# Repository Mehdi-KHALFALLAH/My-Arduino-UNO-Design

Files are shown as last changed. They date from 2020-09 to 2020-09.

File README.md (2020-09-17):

# My-Arduino-UNO-Design

## Contents and Overview

During this project, I deepened and honed my knowledge about ***Altium Designer*** (Version 20.0.10) software and how to do professional PCB design. Altium Designer is a professional software used to design all kinds of boards, from very simple ones to motherboards or servers. It is one of the most used software for electronic design.

I started with Arduino Uno reference schematic. I learned how to re-draw the schematic, modify it, I learned how to improve it and how to do PCB layout. and by the end of the project, I learned what documents are necessary to manufacture the board and how to create them.

during this project, I learned how :

- Draw schematic, including tips for component selection and important circuits
- Create components, draw schematic symbols and footprints
- Place components into your PCB
- Route PCB and useful tips about layout
- Create a 3D model of your board
- Create board variants with different components fitted / not fitted
- Create Bill of Material (BOM)
- Create assembly drawings showing the position of components on the board
- Generate Gerbers, Pick and Place, Drill file, and other files needed for manufacturing
- Prepare professional documents needed to manufacture your PCB and assemble your board

 ## Summary of my project
 
 ### table of contents
 <br />
 
 ***I.  [ Creating my own libraries (schematics, footprints and adding a 3D model to each component) ](#desc)***
 
 ***II. [ Components placement ](#usage)***
 
 ***III. [ Layer's stackup ](#easy)***
 
 ***IV.  [ PCB Layout & Routing ](#hard)***

 ***V.  [ Gerber files, mechanical and assembly drawing ](#medium)***

***VI.   [ 3D model ](#day)***

***VII.  [ VII. Electromagnetic and Signal Integrity (SI) analysis and current density plot with ***ANSYS SIwave***  ](#night)***
<br />
<br />
<br />
<br />
<br />
<br />

## I. Creating my own libraries (schematics, footprints and adding a 3D model to each component)
 
 ### 1 - Designing my first component : the ATMEGA16U2-AU 
 Drawing the schematic and generating the footprint in my own using the Altium tool ***"footprint wizard"***. 
 P.S: footprint's dimensions are taken from the component datasheet :
 
 ATMEGA16U2-AU
 
 ### 2 - Designing the second component : the ATMEGA328P-PU
 
 ATMEGA328P-PU
 
 ### 3 - Designing the female header 1 row x 10 positions (pins)
 
 Female_Header_10Pins
 
 ### 4 - Designing the female header 1 row x 8 positions (pins)
 
8 Pos Female SIL Vertical Throughboard Conn

 ### 5 - Designing the female header 1 row x 6 positions (pins)
 
 Female_Header_6Pins
 
 ### 5 - Designing the 100nF capacitor 
 
 CAP 100n
 
 ### 6 - Sesigning the 10uF capacitor with 1.45mm height 
 
 Cap 10uF_145_height

### 7 - Designing the 1M resistor 

Resistor_1M

### 8 - Designing the 16Mhz crystal 

16MHz Crystal

### 9 - Designing the Micro USB 

micro_USB

### 10 - Designing the 100uf aluminum clectrolytic Capacitor

alu cap 100uf

### 11 - Designing the linear regulator 3.3V 1.5A

regulator

### 12 - Designing the AND gate 

and gate

### 13 - Designing the Button

button

### 14 - Designing the LED 

LED

### 15 - Designing the male header 2 rows x 3 positions (pins)

header 2w3

### 16 - Designing the male header 2 x 2

male 2x2

### 17 - Designing the male header 1 x 3

1x3 header

### 18 - Successful compilation of the project's schematics

0 error

## II. Components placement

### 19 - Starting the placement of some components on the board 

work in progress more 273 component to place

### 20 - Placement of half of the components
By taking advantage of the altium's features cross probe and components cross selection, i could select components from shematic sheet and at the same time they are selected in the PCB sheet, which make it easier to put couplage capacitors as close as possible to their power pins  

half way

### 21 - Placement of the components is complete 

placement complete_blue

## III. Layer's stackup

### 22 - Layer's stackup in 3D  
standard  dielectric thickness   : 1.6mm 
layer 3D

## IV. PCB Layout & Routing

### 23 - Starting to route long tracks

Starting to route long connections first

### 24 - Routing some long tracks through 2 layers
using vias to go from one layer to onother, I call this the "ping pong" routing

### 25 - Routing 2 tracks through 2 layers (some imporvements are made)

routing 2 connections through 2 layers ( some imporvements are done )

### 26 - Finished routing long connections, short connections and Power connections (Power connections are highlighted in the picture)

Finished routing long connections, short connections and Power connections (Power connections are highlighted in the picture)

### 27 - Finished routing all the connections on the board and debugging and fixing all violations errors one by one

Finished routing all the connections on the board and debugging and fixing all violations errors one by one

### 28 - All rule violations are fixed and the board is validated with 0 errors

all rule violations are fixed and the board is validated with 0 errors

### 29 - Drawing the power and the ground planes on the bottom layer

drawing the power and Ground planes on the bottom layer

### 30 - DRC check with 0 errors after improving layout and finishing drawing power and ground planes

DRC check 0 errors after imroving layout and finishing drawing power and ground planes

### 31 - PCB layout after doing some improvements and drawing all the power and ground planes

PCB layout after doing some improvments and drawing power and ground planes

### 32 - Bottom overlay

bottom overlay

### 33 - Last compile after completing the layout 

Last compile, last check

### 34 - Last design rule check after finishing the layout 

Last design rule check

## V. Gerber files, mechanical and assembly drawing

### 35 - Gerber top layer

Gerber Top Layer

### 36 - Gerber bottom layer

Gerber bottom Layer

### 37 - Gerber top overlay

Gerber Top Overlay

### 38 - Gerber bottom overlay

Gerber Bottom Overlay

### 39 - Gerber mechanical drawing

Gerber Mechanical Drawing

### 40 - Generated PDF mechanical drawing

Generated PDF Mechanical Drawing

### 41 - Generated PDF of the assembly drawing variant fixed 5V

Assembly drawing variant fixed 5

### 42 - Generated PDF of the assembly drawing variant 5V 3V3

Assembly drawing variant 5V 3V3

### 43 - Generated PDF of the assembly top view fixed 5V 

Assembly top view 5V fixed

### 44 - Generated PDF of the assembly top view 5V 3V3

Assembly top view 5V 3V3

## VI. 3D model

### 45 - 3D model of my board in Altium Designer

3D Model in Altium
board behind

## VII. Electromagnetic and Signal Integrity (SI) analysis and current density plot with ***ANSYS SIwave*** 

### 46 - Current density analysis using ANSYS SIwave 

using the advanced simulation software especially designed for PCBs, i could do a current density analysis and generate an easy-to-understand plot

Current-Voltage analysis using SIwave from Ansys

### 47 - Far end crosstalk analysis between traces

far end crosstalk between traces

### 48 - Near end crosstalk violations and warnings

near end crosstalk violations and warnings

### 49 - Trace impedance analysis

trace impedance analysis, some improvements and fixes must be done

trace inpedance analisys, some imporvlements and fices must be done

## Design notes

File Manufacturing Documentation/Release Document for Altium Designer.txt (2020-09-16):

Follow this procedure before releasing files. Confirm every action with your initials and date.
IF ANY CHANGES NEEDS TO BE DONE, START THE PROCEDURE FROM BEGINNING!

The procedure needs to be executed in order as defined here. Start from number 1
--------------------------------------------------------------------------------

1) Right Click on the project -> Compile PCB project
I confirm, the project compiles with no errors: 
YourIntials [12:02:52  08/09/2020]

2) Run Design -> Update PCB Document
I confirm, there are no differences between Schematic and PCB: 
YourIntials [12:05:29  08/09/2020]

3) Impedance
I confirm, I have updated and check track width/gap to match required impedance (e.g 55 OHMs): 
NA

4) Run Tools -> Polygon Pours -> Rebuild All
I confirm, all polygons have been repoured: 
YourIntials [12:06:42  08/09/2020]

5) Run Tools -> Design Rule Check -> Run Design Rule Check
I confirm, I have checked Design Rule Output File:
YourIntials [12:33:11  08/09/2020]

6) Gerber check
I confirm, I have copied and visually checked gerber files placed in \PCB Manufacturing\Gerber Output\
YourIntials [17:27:11  08/09/2020]

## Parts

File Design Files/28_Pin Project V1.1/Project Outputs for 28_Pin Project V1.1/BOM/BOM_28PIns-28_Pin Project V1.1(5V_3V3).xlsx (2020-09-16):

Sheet: Part List Report
 | Component list |  |  | 28PIns BOM for Variant [5V/3V3] of Project [28_Pin Project V1.1.PrjPcb] (No PCB Document Selected)
 | Source Data From: | 28_Pin Project V1.1.PrjPcb |  |  | Contact : contact.mehdi.khalfallah@gmail.com |  |  | Generated by:
 | Project: | 28_Pin Project V1.1.PrjPcb
 | Variant: | 5V/3V3 |  |  |  |  |  | Ingr.Mehdi Khalfallah
 | Report Date: | 08/09/2020 | 21:15
 | Print Date: | 2020-09-09 | 18:02:05
# | Category | Manufacturer 1 | Manufacturer Part Number 1 | #Column Name Error:' Package / Case | Description | Quantity | Supplier 1 | Supplier Part Number 1 | Supplier Order Qty 1 | Supplier Stock 1 | Supplier Unit Price 1 | Supplier Subtotal 1 | Supplier Currency 1
1 | Aluminum Electrolytic Capacitors |  |  |  | Cap Aluminum 100uF 10V 20% (5 X 5.4mm) SMD 50mA 1000 hr 85°C T/R | 2 | Digi-Key | PCE3867CT-ND
2 | Ceramic Capacitors |  |  |  | TDK - C2012X5R1E105K125AA - SMD Multilayer Ceramic Capacitor, 1 µF, 25 V, 0805 [2012 Metric], ± 10%, X5R, C Series | 1 | Digi-Key | 445-1419-1-ND
3 | Ceramic Capacitors |  |  |  | CERAMIC CAPACITOR, 10UF, 16V, X5R, 20%, 0805, FULL REEL; Product Range:C Series; Capacitance:10 F; Capacitance Tolerance: 20%; Dielectric Characteristic:X5R; Voltage Rating:16V; Ceramic Capacitor Case:0805 [2012 Metric]; MSL:- ;RoHS Compliant: Yes | 7 | Digi-Key | 445-4115-1-ND
4 | Ceramic Capacitors |  |  |  | CAP CER 18PF 50V C0G/NP0 0805 | 4 | Digi-Key | 399-1112-1-ND
5 | Ceramic Capacitors |  |  |  | TDK - C2012X7R1H104K085AA - SMD Multilayer Ceramic Capacitor, 0.1 µF, 50 V, 0805 [2012 Metric], ± 10%, X7R, C Series | 19 | Digi-Key | 445-7534-1-ND
6 | Chip SMD Resistors |  |  |  | Surface Mount Thick Film Resistor, RC Series, 125 mW, - 5%, 150 V, 0805 [2012 Metric] | 1 | Digi-Key | 311-0.0ARCT-ND
7 | Chip SMD Resistors |  |  |  | RESISTOR, 0805 1K 1%, FULL REEL; Product Range:YAGEO - RC Series; Resistance:1kohm; Power Rating:125mW; Resistance Tolerance:± 1%; Resistor Case Style:0805 [2012 Metric]; Resistor Element Material:Thick Film; Temperature Coefficient:± 250ppm/°C; Voltage Rating:150V; Packaging:Tape & Reel; MSL:-; SVHC:No SVHC (16-Dec-2013); External Depth:0.55mm; External Length / Height:2mm; External Width:1.25mm; No. of Pins:2; Operating Temperature Max:155°C; Operating Temperature Min:-55°C; Operating Temperature Range:-55°C to +155°C; Reel Quantity:5000; Resistor Mounting:SMD; Series:RC12H; Temperature Coef | 3 | Digi-Key | 311-1.00KCRCT-ND
8 | Chip SMD Resistors |  |  |  | Res Thick Film 0805 1M Ohm 1% 0.125W(1/8W) ±100ppm/C Epoxy SMD T/R | 2 | Digi-Key | 311-1.00MCRDKR-ND
9 | Chip SMD Resistors |  |  |  | RES SMD 10K OHM 1% 1/8W 0805 | 6 | Digi-Key | 311-10.0KCRDKR-ND
10 | Chip SMD Resistors |  |  |  | RES SMD 22 OHM 1% 1/8W 0805 | 7 | Digi-Key | 311-22.0CRCT-ND
11 | Chip SMD Resistors |  |  |  | YAGEO RC0805FR-07100KL RES, THICK FILM, 100K, 1%, 0.125W, 0805, REEL | 1 | Digi-Key | 311-100KCRCT-ND
12 | Chip SMD Resistors |  |  |  | Surface Mount Thick Film Resistor, RC Series, 560 ohm, 125 mW, - 1%, 150 V, 0805 [2012 Metric] | 5 | Digi-Key | 311-560CRCT-ND
13 | Connectors |  |  |  | CONN IC DIP SOCKET 28POS TIN | 1 | Digi-Key | 3M5480-ND
14 | Connectors |  |  |  | CONN JUMPER SHORTING .100" GOLD | 3 | Digi-Key | S9337-ND
15 | Crystals |  |  |  | ABRACON - ABM7-8.000MHZ-D2Y-T - Crystal, Miniature, 8 MHz, SMD, 6mm x 3.5mm, 30 ppm, 18 pF, 20 ppm, ABM7 Series | 1 | Digi-Key | 535-9831-1-ND
16 | Crystals |  |  |  | CRYSTAL 10.0000MHZ 18PF SMD | 1 | Digi-Key | 535-9833-1-ND
17 | Ferrite Beads and Chips |  |  |  | FERRITE BEAD 600 OHM 0805 1LN | 3 | Digi-Key | 445-2206-2-ND
18 | Fixed Inductors |  |  |  | FIXED IND 2.2UH 2A 80 MOHM SMD | 1 | Digi-Key | 399-9598-1-ND
19 | Headers and Wire Housings |  |  |  | CONN HEADER VERT 4POS 2.54MM | 1 | Digi-Key | 609-3402-ND
20 | Headers and Wire Housings |  |  |  | CONN HEADER 6POS .100 STR 30AU | 2 | Digi-Key | 609-3393-ND
21 | Headers and Wire Housings |  |  |  | Conn Unshrouded Header HDR 3 POS 2.54mm Solder ST Thru-Hole Bulk | 2 | Digi-Key | 609-3461-ND
22 | Headers and Wire Housings |  |  |  | 2.54mm (0.1") Pitch SIL Vertical PC Tail Socket Assembly, selective gold + tin, 8 contacts | 2 | Digi-Key | 952-1823-ND
23 | Headers and Wire Housings |  |  |  | 06-WAY SIL VERT SOCKET L/FREE | 1 | Digi-Key | 952-1809-ND
24 | Headers and Wire Housings |  |  |  | HARWIN - M20-7821046 - Board-To-Board Connector, M20 Series, Through Hole, Receptacle, 10, 2.54 mm, Tin Plated Contacts | 1 | Digi-Key | 952-1847-ND
25 | Logic Gates |  |  |  | TEXAS INSTRUMENTS - SN74AHC1G09DBVR - AND Gate, 74AHC1G09, 2 Input, 2 V to 5.5 V, SOT-23-5 | 4 | Digi-Key | 296-29202-1-ND
26 | Microcontrollers |  |  |  | MICROCHIP - ATMEGA16U2-AU - MCU, 8BIT, MEGAAVR, 16MHZ, TQFP-32 | 1 | Digi-Key | ATMEGA16U2-AU-ND
27 | Microcontrollers |  |  |  | ATMEGA328P-PU; 8 bit Microcontroller AVR 20MHz 1; 32kb Flash; 2kb RAM; I2C SPI 2 | 1 | Digi-Key | ATMEGA328P-PU-ND
28 | Pushbutton Switches |  |  |  | SWITCH TACTILE SPST-NO 0.05A 24V | 2 | Digi-Key | 450-1650-ND
29 | Schottky Diodes |  |  |  | Small Signal Schottky Diode, Single, 30 V, 200 mA, 800 mV, 600 mA, 150 C ;RoHS Compliant: Yes | 2 | Digi-Key | BAT54HT1GOSCT-ND
30 | Uncategorized |  |  |  | LED Uni-Color Green 572nm 2-Pin Chip 0603(1608Metric) T/R | 1 | Digi-Key | 475-2709-1-ND
31 | Uncategorized |  |  |  | OSRAM - LO L29K-H2K1-24-Z - SMARTLED 0603 ORANGE | 3 | Digi-Key | 475-2740-1-ND
32 | USB Connectors |  |  |  | CONN USB MICRO B RECPT SMT R/A | 1 | Digi-Key | 609-4616-1-ND
33 | Varistors |  |  |  | VARISTOR 0603 | 2 | Digi-Key | CG0603MLC-05ECT-ND
34 | Voltage Regulators - Linear |  |  |  | IC REG LINEAR 3.3V 1.5A SOT223-6 | 1 | Digi-Key | 296-24534-1-ND
 |  |  |  |  |  | 95 |  |  | 0 |  |  | 0
Approved |  |  |  | Notes
 |  |  |  |  |  | 1000 | pcs: | Total |  | 0 |  | USD
 |  |  |  |  |  |  |  | Price for 1pcs |  | 0.00 |  | USD

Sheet: Project Information
Project Full Path | C:\Users\USER\Desktop\altium designer projects\28Pins\Design Files\28_Pin Project V1.1\28_Pin Project V1.1.PrjPcb
Project Filename | 28_Pin Project V1.1.PrjPcb
Variant Name | 5V/3V3
Data-Source Filename | 28_Pin Project V1.1.PrjPcb
Data-Source Full Path | C:\Users\USER\Desktop\altium designer projects\28Pins\Design Files\28_Pin Project V1.1\28_Pin Project V1.1.PrjPcb
Title | 28PIns BOM for Variant [5V/3V3] of Project [28_Pin Project V1.1.PrjPcb] (No PCB Document Selected)
Total Quantity | 95
Report Time | 21:15
Report Date | 08/09/2020
Report Date & Tine | 08/09/2020 21:15
Output Name | 28PIns BOM
Output Type | BOM_PartType
Output Generator Name | BOM
Output Generator Description | Bill of Materials

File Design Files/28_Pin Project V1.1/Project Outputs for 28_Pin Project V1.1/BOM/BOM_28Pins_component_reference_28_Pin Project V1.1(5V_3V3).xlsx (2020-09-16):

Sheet: Part List Report
 | Component reference list |  |  | <Parameter Project not found>
 |  | Source Data From: | 28_Pin Project V1.1.PrjPcb | Contact: contact.mehdi.khalfallah@gmail.com |  | Generated by:
 |  | Project: | 28_Pin Project V1.1.PrjPcb
 |  | Variant: | 5V/3V3 |  |  | Ingr.Mehdi Khalfallah
 | Report Date: | 08/09/2020 | 21:13
 | Print Date: | 2020-09-09 | 17:57:16
# | Designator | Comment | Description | Manufacturer 1 | Manufacturer Part Number 1 | #Column Name Error:' Package / Case | Supplier 1 | Supplier Part Number 1
1 | C1 | 100uF/10V | Cap Aluminum 100uF 10V 20% (5 X 5.4mm) SMD 50mA 1000 hr 85°C T/R |  |  |  | Digi-Key | PCE3867CT-ND
2 | C2 | 100uF/10V | Cap Aluminum 100uF 10V 20% (5 X 5.4mm) SMD 50mA 1000 hr 85°C T/R |  |  |  | Digi-Key | PCE3867CT-ND
3 | C3 | 10uF/16V | CERAMIC CAPACITOR, 10UF, 16V, X5R, 20%, 0805, FULL REEL; Product Range:C Series; Capacitance:10 F; Capacitance Tolerance: 20%; Dielectric Characteristic:X5R; Voltage Rating:16V; Ceramic Capacitor Case:0805 [2012 Metric]; MSL:- ;RoHS Compliant: Yes |  |  |  | Digi-Key | 445-4115-1-ND
4 | C4 | 100nF | TDK - C2012X7R1H104K085AA - SMD Multilayer Ceramic Capacitor, 0.1 µF, 50 V, 0805 [2012 Metric], ± 10%, X7R, C Series |  |  |  | Digi-Key | 445-7534-1-ND
5 | C5 | 100nF | TDK - C2012X7R1H104K085AA - SMD Multilayer Ceramic Capacitor, 0.1 µF, 50 V, 0805 [2012 Metric], ± 10%, X7R, C Series |  |  |  | Digi-Key | 445-7534-1-ND
6 | C6 | 100nF | TDK - C2012X7R1H104K085AA - SMD Multilayer Ceramic Capacitor, 0.1 µF, 50 V, 0805 [2012 Metric], ± 10%, X7R, C Series |  |  |  | Digi-Key | 445-7534-1-ND
7 | C7 | 1u/25V | TDK - C2012X5R1E105K125AA - SMD Multilayer Ceramic Capacitor, 1 µF, 25 V, 0805 [2012 Metric], ± 10%, X5R, C Series |  |  |  | Digi-Key | 445-1419-1-ND
8 | C8 | 100nF | TDK - C2012X7R1H104K085AA - SMD Multilayer Ceramic Capacitor, 0.1 µF, 50 V, 0805 [2012 Metric], ± 10%, X7R, C Series |  |  |  | Digi-Key | 445-7534-1-ND
9 | C9 | 18p | CAP CER 18PF 50V C0G/NP0 0805 |  |  |  | Digi-Key | 399-1112-1-ND
10 | C10 | 18p | CAP CER 18PF 50V C0G/NP0 0805 |  |  |  | Digi-Key | 399-1112-1-ND
11 | C11 | 100nF | TDK - C2012X7R1H104K085AA - SMD Multilayer Ceramic Capacitor, 0.1 µF, 50 V, 0805 [2012 Metric], ± 10%, X7R, C Series |  |  |  | Digi-Key | 445-7534-1-ND
12 | C12 | 10uF/16V | CERAMIC CAPACITOR, 10UF, 16V, X5R, 20%, 0805, FULL REEL; Product Range:C Series; Capacitance:10 F; Capacitance Tolerance: 20%; Dielectric Characteristic:X5R; Voltage Rating:16V; Ceramic Capacitor Case:0805 [2012 Metric]; MSL:- ;RoHS Compliant: Yes |  |  |  | Digi-Key | 445-4115-1-ND
13 | C13 | 10uF/16V | CERAMIC CAPACITOR, 10UF, 16V, X5R, 20%, 0805, FULL REEL; Product Range:C Series; Capacitance:10 F; Capacitance Tolerance: 20%; Dielectric Characteristic:X5R; Voltage Rating:16V; Ceramic Capacitor Case:0805 [2012 Metric]; MSL:- ;RoHS Compliant: Yes |  |  |  | Digi-Key | 445-4115-1-ND
14 | C14 | 100nF | TDK - C2012X7R1H104K085AA - SMD Multilayer Ceramic Capacitor, 0.1 µF, 50 V, 0805 [2012 Metric], ± 10%, X7R, C Series |  |  |  | Digi-Key | 445-7534-1-ND
15 | C15 | 100nF | TDK - C2012X7R1H104K085AA - SMD Multilayer Ceramic Capacitor, 0.1 µF, 50 V, 0805 [2012 Metric], ± 10%, X7R, C Series |  |  |  | Digi-Key | 445-7534-1-ND
16 | C16 | 100nF | TDK - C2012X7R1H104K085AA - SMD Multilayer Ceramic Capacitor, 0.1 µF, 50 V, 0805 [2012 Metric], ± 10%, X7R, C Series |  |  |  | Digi-Key | 445-7534-1-ND
17 | C17 | 100nF | TDK - C2012X7R1H104K085AA - SMD Multilayer Ceramic Capacitor, 0.1 µF, 50 V, 0805 [2012 Metric], ± 10%, X7R, C Series |  |  |  | Digi-Key | 445-7534-1-ND
18 | C19 | 10uF/16V | CERAMIC CAPACITOR, 10UF, 16V, X5R, 20%, 0805, FULL REEL; Product Range:C Series; Capacitance:10 F; Capacitance Tolerance: 20%; Dielectric Characteristic:X5R; Voltage Rating:16V; Ceramic Capacitor Case:0805 [2012 Metric]; MSL:- ;RoHS Compliant: Yes |  |  |  | Digi-Key | 445-4115-1-ND
19 | C20 | 100nF | TDK - C2012X7R1H104K085AA - SMD Multilayer Ceramic Capacitor, 0.1 µF, 50 V, 0805 [2012 Metric], ± 10%, X7R, C Series |  |  |  | Digi-Key | 445-7534-1-ND
20 | C21 | 10uF/16V | CERAMIC CAPACITOR, 10UF, 16V, X5R, 20%, 0805, FULL REEL; Product Range:C Series; Capacitance:10 F; Capacitance Tolerance: 20%; Dielectric Characteristic:X5R; Voltage Rating:16V; Ceramic Capacitor Case:0805 [2012 Metric]; MSL:- ;RoHS Compliant: Yes |  |  |  | Digi-Key | 445-4115-1-ND
21 | C22 | 10uF/16V | CERAMIC CAPACITOR, 10UF, 16V, X5R, 20%, 0805, FULL REEL; Product Range:C Series; Capacitance:10 F; Capacitance Tolerance: 20%; Dielectric Characteristic:X5R; Voltage Rating:16V; Ceramic Capacitor Case:0805 [2012 Metric]; MSL:- ;RoHS Compliant: Yes |  |  |  | Digi-Key | 445-4115-1-ND
22 | C23 | 100nF | TDK - C2012X7R1H104K085AA - SMD Multilayer Ceramic Capacitor, 0.1 µF, 50 V, 0805 [2012 Metric], ± 10%, X7R, C Series |  |  |  | Digi-Key | 445-7534-1-ND
23 | C24 | 100nF | TDK - C2012X7R1H104K085AA - SMD Multilayer Ceramic Capacitor, 0.1 µF, 50 V, 0805 [2012 Metric], ± 10%, X7R, C Series |  |  |  | Digi-Key | 445-7534-1-ND
24 | C25 | 18p | CAP CER 18PF 50V C0G/NP0 0805 |  |  |  | Digi-Key | 399-1112-1-ND
25 | C26 | 100nF | TDK - C2012X7R1H104K085AA - SMD Multilayer Ceramic Capacitor, 0.1 µF, 50 V, 0805 [2012 Metric], ± 10%, X7R, C Series |  |  |  | Digi-Key | 445-7534-1-ND
26 | C27 | 18p | CAP CER 18PF 50V C0G/NP0 0805 |  |  |  | Digi-Key | 399-1112-1-ND
27 | C28 | 100nF | TDK - C2012X7R1H104K085AA - SMD Multilayer Ceramic Capacitor, 0.1 µF, 50 V, 0805 [2012 Metric], ± 10%, X7R, C Series |  |  |  | Digi-Key | 445-7534-1-ND
28 | C29 | 100nF | TDK - C2012X7R1H104K085AA - SMD Multilayer Ceramic Capacitor, 0.1 µF, 50 V, 0805 [2012 Metric], ± 10%, X7R, C Series |  |  |  | Digi-Key | 445-7534-1-ND
29 | C30 | 100nF | TDK - C2012X7R1H104K085AA - SMD Multilayer Ceramic Capacitor, 0.1 µF, 50 V, 0805 [2012 Metric], ± 10%, X7R, C Series |  |  |  | Digi-Key | 445-7534-1-ND
30 | C31 | 100nF | TDK - C2012X7R1H104K085AA - SMD Multilayer Ceramic Capacitor, 0.1 µF, 50 V, 0805 [2012 Metric], ± 10%, X7R, C Series |  |  |  | Digi-Key | 445-7534-1-ND
31 | C32 | 100nF | TDK - C2012X7R1H104K085AA - SMD Multilayer Ceramic Capacitor, 0.1 µF, 50 V, 0805 [2012 Metric], ± 10%, X7R, C Series |  |  |  | Digi-Key | 445-7534-1-ND
32 | C33 | 100nF | TDK - C2012X7R1H104K085AA - SMD Multilayer Ceramic Capacitor, 0.1 µF, 50 V, 0805 [2012 Metric], ± 10%, X7R, C Series |  |  |  | Digi-Key | 445-7534-1-ND
33 | C34 | 10uF/16V | CERAMIC CAPACITOR, 10UF, 16V, X5R, 20%, 0805, FULL REEL; Product Range:C Series; Capacitance:10 F; Capacitance Tolerance: 20%; Dielectric Characteristic:X5R; Voltage Rating:16V; Ceramic Capacitor Case:0805 [2012 Metric]; MSL:- ;RoHS Compliant: Yes |  |  |  | Digi-Key | 445-4115-1-ND
34 | D1 | GREEN | LED Uni-Color Green 572nm 2-Pin Chip 0603(1608Metric) T/R |  |  |  | Digi-Key | 475-2709-1-ND
35 | D2 | Orange | OSRAM - LO L29K-H2K1-24-Z - SMARTLED 0603 ORANGE |  |  |  | Digi-Key | 475-2740-1-ND
36 | D3 | Orange | OSRAM - LO L29K-H2K1-24-Z - SMARTLED 0603 ORANGE |  |  |  | Digi-Key | 475-2740-1-ND
37 | D4 | Orange | OSRAM - LO L29K-H2K1-24-Z - SMARTLED 0603 ORANGE |  |  |  | Digi-Key | 475-2740-1-ND
38 | D5 | BAT54HT1G: Schottky Diode | Small Signal Schottky Diode, Single, 30 V, 200 mA, 800 mV, 600 mA, 150 C ;RoHS Compliant: Yes |  |  |  | Digi-Key | BAT54HT1GOSCT-ND
39 | D6 | BAT54HT1G: Schottky Diode | Small Signal Schottky Diode, Single, 30 V, 200 mA, 800 mV, 600 mA, 150 C ;RoHS Compliant: Yes |  |  |  | Digi-Key | BAT54HT1GOSCT-ND
40 | FB1 | FERRITE BEAD 600 OHM 0805 1LN | FERRITE BEAD 600 OHM 0805 1LN |  |  |  | Digi-Key | 445-2206-2-ND
41 | FB2 | FERRITE BEAD 600 OHM 0805 1LN | FERRITE BEAD 600 OHM 0805 1LN |  |  |  | Digi-Key | 445-2206-2-ND
42 | FB3 | FERRITE BEAD 600 OHM 0805 1LN | FERRITE BEAD 600 OHM 0805 1LN |  |  |  | Digi-Key | 445-2206-2-ND
43 | J1 | HDR Female 1×8 2.54mm | 2.54mm (0.1") Pitch SIL Vertical PC Tail Socket Assembly, selective gold + tin, 8 contacts |  |  |  | Digi-Key | 952-1823-ND
44 | J2 | HDR Female 6×1 2.54mm | 06-WAY SIL VERT SOCKET L/FREE |  |  |  | Digi-Key | 952-1809-ND
45 | J3 | HDR Female 1×8 2.54mm | 2.54mm (0.1") Pitch SIL Vertical PC Tail Socket Assembly, selective gold + tin, 8 contacts |  |  |  | Digi-Key | 952-1823-ND
46 | J4 | HDR Female Single Row 10 contacts 2.55mm | HARWIN - M20-7821046 - Board-To-Board Connector, M20 Series, Through Hole, Receptacle, 10, 2.54 mm, Tin Plated Contacts |  |  |  | Digi-Key | 952-1847-ND
47 | J5 | HDR 2x3 | CONN HEADER 6POS .100 STR 30AU |  |  |  | Digi-Key | 609-3393-ND
48 | J6 | HDR 2x3 | CONN HEADER 6POS .100 STR 30AU |  |  |  | Digi-Key | 609-3393-ND
49 | J7 | 10118193-0001LF | CONN USB MICRO B RECPT SMT R/A |  |  |  | Digi-Key | 609-4616-1-ND
50 | JP1 | HDR 3x1 | Conn Unshrouded Header HDR 3 POS 2.54mm Solder ST Thru-Hole Bulk |  |  |  | Digi-Key | 609-3461-ND
51 | JP3 | HDR 1x4 | CONN HEADER VERT 4POS 2.54MM |  |  |  | Digi-Key | 609-3402-ND
52 | JP4 | HDR 3x1 | Conn Unshrouded Header HDR 3 POS 2.54mm Solder ST Thru-Hole Bulk |  |  |  | Digi-Key | 609-3461-ND
53 | L1 | 2u2/2A | FIXED IND 2.2UH 2A 80 MOHM SMD |  |  |  | Digi-Key | 399-9598-1-ND
54 | LINK1 | LINK | CONN JUMPER SHORTING .100" GOLD |  |  |  | Digi-Key | S9337-ND
55 | LINK2 | LINK | CONN JUMPER SHORTING .100" GOLD |  |  |  | Digi-Key | S9337-ND
56 | LINK3 | LINK | CONN JUMPER SHORTING .100" GOLD |  |  |  | Digi-Key | S9337-ND
57 | R1 | 100K R | YAGEO RC0805FR-07100KL RES, THICK FILM, 100K, 1%, 0.125W, 0805, REEL |  |  |  | Digi-Key | 311-100KCRCT-ND
58 | R2 | 560R_Resistor | Surface Mount Thick Film Resistor, RC Series, 560 ohm, 125 mW, - 1%, 150 V, 0805 [2012 Metric] |  |  |  | Digi-Key | 311-560CRCT-ND
59 | R3 | 560R_Resistor | Surface Mount Thick Film Resistor, RC Series, 560 ohm, 125 mW, - 1%, 150 V, 0805 [2012 Metric] |  |  |  | Digi-Key | 311-560CRCT-ND
60 | R4 | 10K | RES SMD 10K OHM 1% 1/8W 0805 |  |  |  | Digi-Key | 311-10.0KCRDKR-ND
61 | R5 | 22R | RES SMD 22 OHM 1% 1/8W 0805 |  |  |  | Digi-Key | 311-22.0CRCT-ND
62 | R6 | 22R | RES SMD 22 OHM 1% 1/8W 0805 |  |  |  | Digi-Key | 311-22.0CRCT-ND
63 | R7 | 22R | RES SMD 22 OHM 1% 1/8W 0805 |  |  |  | Digi-Key | 311-22.0CRCT-ND
64 | R8 | 0R | Surface Mount Thick Film Resistor, RC Series, 125 mW, - 5%, 150 V, 0805 [2012 Metric] |  |  |  | Digi-Key | 311-0.0ARCT-ND
65 | R9 | 1M | Res Thick Film 0805 1M Ohm 1% 0.125W(1/8W) ±100ppm/C Epoxy SMD T/R |  |  |  | Digi-Key | 311-1.00MCRDKR-ND
66 | R10 | 1K | RESISTOR, 0805 1K 1%, FULL REEL; Product Range:YAGEO - RC Series; Resistance:1kohm; Power Rating:125mW; Resistance Tolerance:± 1%; Resistor Case Style:0805 [2012 Metric]; Resistor Element Material:Thick Film; Temperature Coefficient:± 250ppm/°C; Voltage Rating:150V; Packaging:Tape & Reel; MSL:-; SVHC:No SVHC (16-Dec-2013); External Depth:0.55mm; External Length / Height:2mm; External Width:1.25mm; No. of Pins:2; Operating Temperature Max:155°C; Operating Temperature Min:-55°C; Operating Temperature Range:-55°C to +155°C; Reel Quantity:5000; Resistor Mounting:SMD; Series:RC12H; Temperature Coef |  |  |  | Digi-Key | 311-1.00KCRCT-ND
67 | R11 | 1K | RESISTOR, 0805 1K 1%, FULL REEL; Product Range:YAGEO - RC Series; Resistance:1kohm; Power Rating:125mW; Resistance Tolerance:± 1%; Resistor Case Style:0805 [2012 Metric]; Resistor Element Material:Thick Film; Temperature Coefficient:± 250ppm/°C; Voltage Rating:150V; Packaging:Tape & Reel; MSL:-; SVHC:No SVHC (16-Dec-2013); External Depth:0.55mm; External Length / Height:2mm; External Width:1.25mm; No. of Pins:2; Operating Temperature Max:155°C; Operating Temperature Min:-55°C; Operating Temperature Range:-55°C to +155°C; Reel Quantity:5000; Resistor Mounting:SMD; Series:RC12H; Temperature Coef |  |  |  | Digi-Key | 311-1.00KCRCT-ND
68 | R12 | 1K | RESISTOR, 0805 1K 1%, FULL REEL; Product Range:YAGEO - RC Series; Resistance:1kohm; Power Rating:125mW; Resistance Tolerance:± 1%; Resistor Case Style:0805 [2012 Metric]; Resistor Element Material:Thick Film; Temperature Coefficient:± 250ppm/°C; Voltage Rating:150V; Packaging:Tape & Reel; MSL:-; SVHC:No SVHC (16-Dec-2013); External Depth:0.55mm; External Length / Height:2mm; External Width:1.25mm; No. of Pins:2; Operating Temperature Max:155°C; Operating Temperature Min:-55°C; Operating Temperature Range:-55°C to +155°C; Reel Quantity:5000; Resistor Mounting:SMD; Series:RC12H; Temperature Coef |  |  |  | Digi-Key | 311-1.00KCRCT-ND
69 | R13 | 22R | RES SMD 22 OHM 1% 1/8W 0805 |  |  |  | Digi-Key | 311-22.0CRCT-ND
70 | R14 | 10K | RES SMD 10K OHM 1% 1/8W 0805 |  |  |  | Digi-Key | 311-10.0KCRDKR-ND
71 | R15 | 560R_Resistor | Surface Mount Thick Film Resistor, RC Series, 560 ohm, 125 mW, - 1%, 150 V, 0805 [2012 Metric] |  |  |  | Digi-Key | 311-560CRCT-ND
72 | R16 | 1M | Res Thick Film 0805 1M Ohm 1% 0.125W(1/8W) ±100ppm/C Epoxy SMD T/R |  |  |  | Digi-Key | 311-1.00MCRDKR-ND
73 | R17 | 560R_Resistor | Surface Mount Thick Film Resistor, RC Series, 560 ohm, 125 mW, - 1%, 150 V, 0805 [2012 Metric] |  |  |  | Digi-Key | 311-560CRCT-ND
74 | R18 | 10K | RES SMD 10K OHM 1% 1/8W 0805 |  |  |  | Digi-Key | 311-10.0KCRDKR-ND
75 | R19 | 10K | RES SMD 10K OHM 1% 1/8W 0805 |  |  |  | Digi-Key | 311-10.0KCRDKR-ND
76 | R20 | 10K | RES SMD 10K OHM 1% 1/8W 0805 |  |  |  | Digi-Key | 311-10.0KCRDKR-ND
77 | R21 | 10K | RES SMD 10K OHM 1% 1/8W 0805 |  |  |  | Digi-Key | 311-10.0KCRDKR-ND
78 | R22 | 560R_Resistor | Surface Mount Thick Film Resistor, RC Series, 560 ohm, 125 mW, - 1%, 150 V, 0805 [2012 Metric] |  |  |  | Digi-Key | 311-560CRCT-ND
79 | R23 | 22R | RES SMD 22 OHM 1% 1/8W 0805 |  |  |  | Digi-Key | 311-22.0CRCT-ND
80 | R24 | 22R | RES SMD 22 OHM 1% 1/8W 0805 |  |  |  | Digi-Key | 311-22.0CRCT-ND
81 | R25 | 22R | RES SMD 22 OHM 1% 1/8W 0805 |  |  |  | Digi-Key | 311-22.0CRCT-ND
82 | SCKT FOR U1 | 28-DIP-SOCKET | CONN IC DIP SOCKET 28POS TIN |  |  |  | Digi-Key | 3M5480-ND
83 | SW1 | Button | SWITCH TACTILE SPST-NO 0.05A 24V |  |  |  | Digi-Key | 450-1650-ND
84 | SW2 | Button | SWITCH TACTILE SPST-NO 0.05A 24V |  |  |  | Digi-Key | 450-1650-ND
85 | U1 | ATMEGA328P-PU | ATMEGA328P-PU; 8 bit Microcontroller AVR 20MHz 1; 32kb Flash; 2kb RAM; I2C SPI 2 |  |  |  | Digi-Key | ATMEGA328P-PU-ND
86 | U2 | ATMEGA16U2-AU | MICROCHIP - ATMEGA16U2-AU - MCU, 8BIT, MEGAAVR, 16MHZ, TQFP-32 |  |  |  | Digi-Key | ATMEGA16U2-AU-ND
87 | U3 | TL1963A-33DCQR | IC REG LINEAR 3.3V 1.5A SOT223-6 |  |  |  | Digi-Key | 296-24534-1-ND
88 | U4 | AND_SN74AHC1G09DBVR | TEXAS INSTRUMENTS - SN74AHC1G09DBVR - AND Gate, 74AHC1G09, 2 Input, 2 V to 5.5 V, SOT-23-5 |  |  |  | Digi-Key | 296-29202-1-ND
89 | U5 | AND_SN74AHC1G09DBVR | TEXAS INSTRUMENTS - SN74AHC1G09DBVR - AND Gate, 74AHC1G09, 2 Input, 2 V to 5.5 V, SOT-23-5 |  |  |  | Digi-Key | 296-29202-1-ND
90 | U6 | AND_SN74AHC1G09DBVR | TEXAS INSTRUMENTS - SN74AHC1G09DBVR - AND Gate, 74AHC1G09, 2 Input, 2 V to 5.5 V, SOT-23-5 |  |  |  | Digi-Key | 296-29202-1-ND
91 | U7 | AND_SN74AHC1G09DBVR | TEXAS INSTRUMENTS - SN74AHC1G09DBVR - AND Gate, 74AHC1G09, 2 Input, 2 V to 5.5 V, SOT-23-5 |  |  |  | Digi-Key | 296-29202-1-ND
92 | Y1 | ABM7-10.000MHZ-D2Y-T | CRYSTAL 10.0000MHZ 18PF SMD |  |  |  | Digi-Key | 535-9833-1-ND
93 | Y2 | ABM7-8.000MHZ-D2Y-T | ABRACON - ABM7-8.000MHZ-D2Y-T - Crystal, Miniature, 8 MHz, SMD, 6mm x 3.5mm, 30 ppm, 18 pF, 20 ppm, ABM7 Series |  |  |  | Digi-Key | 535-9831-1-ND
94 | Z1 | CG0603MLC-05E | VARISTOR 0603 |  |  |  | Digi-Key | CG0603MLC-05ECT-ND
95 | Z2 | CG0603MLC-05E | VARISTOR 0603 |  |  |  | Digi-Key | CG0603MLC-05ECT-ND
Approved |  |  |  | Notes

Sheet: Project Information
Project Full Path | C:\Users\USER\Desktop\altium designer projects\28Pins\Design Files\28_Pin Project V1.1\28_Pin Project V1.1.PrjPcb
Project Filename | 28_Pin Project V1.1.PrjPcb
Variant Name | 5V/3V3
Data-Source Filename | 28_Pin Project V1.1.PrjPcb
Data-Source Full Path | C:\Users\USER\Desktop\altium designer projects\28Pins\Design Files\28_Pin Project V1.1\28_Pin Project V1.1.PrjPcb
Title | 28_Pin Project V1.1.PrjPcb
Total Quantity | 95
Report Time | 21:13
Report Date | 08/09/2020
Report Date & Tine | 08/09/2020 21:13
Output Name | 28Pins_component_reference_BOM
Output Type | BOM_PartType
Output Generator Name | BOM
Output Generator Description | Bill of Materials

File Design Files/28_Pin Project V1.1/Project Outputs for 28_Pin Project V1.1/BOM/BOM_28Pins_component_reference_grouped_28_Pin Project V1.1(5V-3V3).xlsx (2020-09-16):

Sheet: Part List Report
 | Component reference list (grouped) |  |  |  | <Parameter Project not found>
 | Source Data From: |  | 28_Pin Project V1.1.PrjPcb |  | contact: Contact.mehdi.khalfallah@gmail.com |  | Generated by:
 | Project: |  | 28_Pin Project V1.1.PrjPcb
 | Variant: |  | 5V/3V3 |  |  |  | Ingr. Mehdi Khalfallah
 | Report Date: |  | 08/09/2020 | 23:26
 | Print Date: |  | 2020-09-09 | 18:00:08
# | Designator | Quantity | Comment | Description | Manufacturer 1 | Manufacturer Part Number 1 | #Column Name Error:' Package / Case | Supplier 1 | Supplier Part Number 1
1 | C1, C2 | 2 | 100uF/10V | Cap Aluminum 100uF 10V 20% (5 X 5.4mm) SMD 50mA 1000 hr 85°C T/R | Panasonic | EEE-1AA101WR |  | Digi-Key | PCE3867CT-ND
2 | C3, C12, C13, C19, C21, C22, C34 | 7 | 10uF/16V | CERAMIC CAPACITOR, 10UF, 16V, X5R, 20%, 0805, FULL REEL; Product Range:C Series; Capacitance:10 F; Capacitance Tolerance: 20%; Dielectric Characteristic:X5R; Voltage Rating:16V; Ceramic Capacitor Case:0805 [2012 Metric]; MSL:- ;RoHS Compliant: Yes | TDK | C2012X5R1C106M125AC |  | Digi-Key | 445-4115-1-ND
3 | C4, C5, C6, C8, C11, C14, C15, C16, C17, C20, C23, C24, C26, C28, C29, C30, C31, C32, C33 | 19 | 100nF | TDK - C2012X7R1H104K085AA - SMD Multilayer Ceramic Capacitor, 0.1 µF, 50 V, 0805 [2012 Metric], ± 10%, X7R, C Series | TDK | C2012X7R1H104K085AA |  | Digi-Key | 445-7534-1-ND
4 | C7 | 1 | 1u/25V | TDK - C2012X5R1E105K125AA - SMD Multilayer Ceramic Capacitor, 1 µF, 25 V, 0805 [2012 Metric], ± 10%, X5R, C Series | TDK | C2012X5R1E105K125AA |  | Digi-Key | 445-1419-1-ND
5 | C9, C10, C25, C27 | 4 | 18p | CAP CER 18PF 50V C0G/NP0 0805 | KEMET | C0805C180J5GACTU |  | Digi-Key | 399-1112-1-ND
6 | D1 | 1 | GREEN | LED Uni-Color Green 572nm 2-Pin Chip 0603(1608Metric) T/R | Osram Opto | LGL29K-G2J1-24-Z |  | Digi-Key | 475-2709-1-ND
7 | D2, D3, D4 | 3 | Orange | OSRAM - LO L29K-H2K1-24-Z - SMARTLED 0603 ORANGE | Osram Opto | LOL29K-H2K1-24-Z |  | Digi-Key | 475-2740-1-ND
8 | D5, D6 | 2 | BAT54HT1G: Schottky Diode | Small Signal Schottky Diode, Single, 30 V, 200 mA, 800 mV, 600 mA, 150 C ;RoHS Compliant: Yes | ON Semiconductor / Fairchild | BAT54HT1G |  | Digi-Key | BAT54HT1GOSCT-ND
9 | FB1, FB2, FB3 | 3 | FERRITE BEAD 600 OHM 0805 1LN | FERRITE BEAD 600 OHM 0805 1LN | TDK | MPZ2012S601AT000 |  | Digi-Key | 445-2206-2-ND
10 | J1, J3 | 2 | HDR Female 1×8 2.54mm | 2.54mm (0.1") Pitch SIL Vertical PC Tail Socket Assembly, selective gold + tin, 8 contacts | Harwin | M20-7820842 |  | Digi-Key | 952-1823-ND
11 | J2 | 1 | HDR Female 6×1 2.54mm | 06-WAY SIL VERT SOCKET L/FREE | Harwin | M20-7820646 |  | Digi-Key | 952-1809-ND
12 | J4 | 1 | HDR Female Single Row 10 contacts 2.55mm | HARWIN - M20-7821046 - Board-To-Board Connector, M20 Series, Through Hole, Receptacle, 10, 2.54 mm, Tin Plated Contacts | Harwin | M20-7821046 |  | Digi-Key | 952-1847-ND
13 | J5, J6 | 2 | HDR 2x3 | CONN HEADER 6POS .100 STR 30AU | Amphenol ICC / FCI | 67997-106HLF |  | Digi-Key | 609-3393-ND
14 | J7 | 1 | 10118193-0001LF | CONN USB MICRO B RECPT SMT R/A | AMPHENOL ICC (FCI) | 10118193-0001LF |  | Digi-Key | 609-4616-1-ND
15 | JP1, JP4 | 2 | HDR 3x1 | Conn Unshrouded Header HDR 3 POS 2.54mm Solder ST Thru-Hole Bulk | Amphenol ICC | 68000-103HLF |  | Digi-Key | 609-3461-ND
16 | JP3 | 1 | HDR 1x4 | CONN HEADER VERT 4POS 2.54MM | Amphenol FCI | 68001-204HLF |  | Digi-Key | 609-3402-ND
17 | L1 | 1 | 2u2/2A | FIXED IND 2.2UH 2A 80 MOHM SMD | KEMET | L1210R2R2MDWIT |  | Digi-Key | 399-9598-1-ND
18 | LINK1, LINK2, LINK3 | 3 | LINK | CONN JUMPER SHORTING .100" GOLD | Sullins | QPC02SXGN-RC |  | Digi-Key | S9337-ND
19 | R1 | 1 | 100K R | YAGEO RC0805FR-07100KL RES, THICK FILM, 100K, 1%, 0.125W, 0805, REEL | Yageo | RC0805FR-07100KL |  | Digi-Key | 311-100KCRCT-ND
20 | R2, R3, R15, R17, R22 | 5 | 560R_Resistor | Surface Mount Thick Film Resistor, RC Series, 560 ohm, 125 mW, - 1%, 150 V, 0805 [2012 Metric] | Yageo | RC0805FR-07560RL |  | Digi-Key | 311-560CRCT-ND
21 | R4, R14, R18, R19, R20, R21 | 6 | 10K | RES SMD 10K OHM 1% 1/8W 0805 | Yageo | RC0805FR-0710KL |  | Digi-Key | 311-10.0KCRDKR-ND
22 | R5, R6, R7, R13, R23, R24, R25 | 7 | 22R | RES SMD 22 OHM 1% 1/8W 0805 | Yageo | RC0805FR-0722RL |  | Digi-Key | 311-22.0CRCT-ND
23 | R8 | 1 | 0R | Surface Mount Thick Film Resistor, RC Series, 125 mW, - 5%, 150 V, 0805 [2012 Metric] | Yageo | RC0805JR-070RL |  | Digi-Key | 311-0.0ARCT-ND
24 | R9, R16 | 2 | 1M | Res Thick Film 0805 1M Ohm 1% 0.125W(1/8W) ±100ppm/C Epoxy SMD T/R | Yageo | RC0805FR-071ML |  | Digi-Key | 311-1.00MCRDKR-ND
25 | R10, R11, R12 | 3 | 1K | RESISTOR, 0805 1K 1%, FULL REEL; Product Range:YAGEO - RC Series; Resistance:1kohm; Power Rating:125mW; Resistance Tolerance:± 1%; Resistor Case Style:0805 [2012 Metric]; Resistor Element Material:Thick Film; Temperature Coefficient:± 250ppm/°C; Voltage Rating:150V; Packaging:Tape & Reel; MSL:-; SVHC:No SVHC (16-Dec-2013); External Depth:0.55mm; External Length / Height:2mm; External Width:1.25mm; No. of Pins:2; Operating Temperature Max:155°C; Operating Temperature Min:-55°C; Operating Temperature Range:-55°C to +155°C; Reel Quantity:5000; Resistor Mounting:SMD; Series:RC12H; Temperature Coef | Yageo | RC0805FR-071KL |  | Digi-Key | 311-1.00KCRCT-ND
26 | SCKT FOR U1 | 1 | 28-DIP-SOCKET | CONN IC DIP SOCKET 28POS TIN | 3M | 7010501790 |  | Digi-Key | 3M5480-ND
27 | SW1, SW2 | 2 | Button | SWITCH TACTILE SPST-NO 0.05A 24V | TE Connectivity | FSM4JH |  | Digi-Key | 450-1650-ND
28 | U1 | 1 | ATMEGA328P-PU | ATMEGA328P-PU; 8 bit Microcontroller AVR 20MHz 1; 32kb Flash; 2kb RAM; I2C SPI 2 | Microchip / Atmel | ATMEGA328P-PU |  | Digi-Key | ATMEGA328P-PU-ND
29 | U2 | 1 | ATMEGA16U2-AU | MICROCHIP - ATMEGA16U2-AU - MCU, 8BIT, MEGAAVR, 16MHZ, TQFP-32 | Microchip | ATMEGA16U2-AU |  | Digi-Key | ATMEGA16U2-AU-ND
30 | U3 | 1 | TL1963A-33DCQR | IC REG LINEAR 3.3V 1.5A SOT223-6 | Texas Instruments | TL1963A-33DCQR |  | Digi-Key | 296-24534-1-ND
31 | U4, U5, U6, U7 | 4 | AND_SN74AHC1G09DBVR | TEXAS INSTRUMENTS - SN74AHC1G09DBVR - AND Gate, 74AHC1G09, 2 Input, 2 V to 5.5 V, SOT-23-5 | Texas Instruments | SN74AHC1G09DBVR |  | Digi-Key | 296-29202-1-ND
32 | Y1 | 1 | ABM7-10.000MHZ-D2Y-T | CRYSTAL 10.0000MHZ 18PF SMD | Abracon | ABM7-10.000MHZ-D2Y-T |  | Digi-Key | 535-9833-1-ND
33 | Y2 | 1 | ABM7-8.000MHZ-D2Y-T | ABRACON - ABM7-8.000MHZ-D2Y-T - Crystal, Miniature, 8 MHz, SMD, 6mm x 3.5mm, 30 ppm, 18 pF, 20 ppm, ABM7 Series | Abracon | ABM7-8.000MHZ-D2Y-T |  | Digi-Key | 535-9831-1-ND
34 | Z1, Z2 | 2 | CG0603MLC-05E | VARISTOR 0603 | Bourns | CG0603MLC-05E |  | Digi-Key | CG0603MLC-05ECT-ND
Approved |  |  |  |  | Notes

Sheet: Project Information
Project Full Path | C:\Users\USER\Desktop\altium designer projects\28Pins\Design Files\28_Pin Project V1.1\28_Pin Project V1.1.PrjPcb
Project Filename | 28_Pin Project V1.1.PrjPcb
Variant Name | 5V/3V3
Data-Source Filename | 28_Pin Project V1.1.PrjPcb
Data-Source Full Path | C:\Users\USER\Desktop\altium designer projects\28Pins\Design Files\28_Pin Project V1.1\28_Pin Project V1.1.PrjPcb
Title | 28_Pin Project V1.1.PrjPcb
Total Quantity | 95
Report Time | 23:26
Report Date | 08/09/2020
Report Date & Tine | 08/09/2020 23:26
Output Name | 28Pins component reference grouped BOM
Output Type | BOM_PartType
Output Generator Name | BOM
Output Generator Description | Bill of Materials

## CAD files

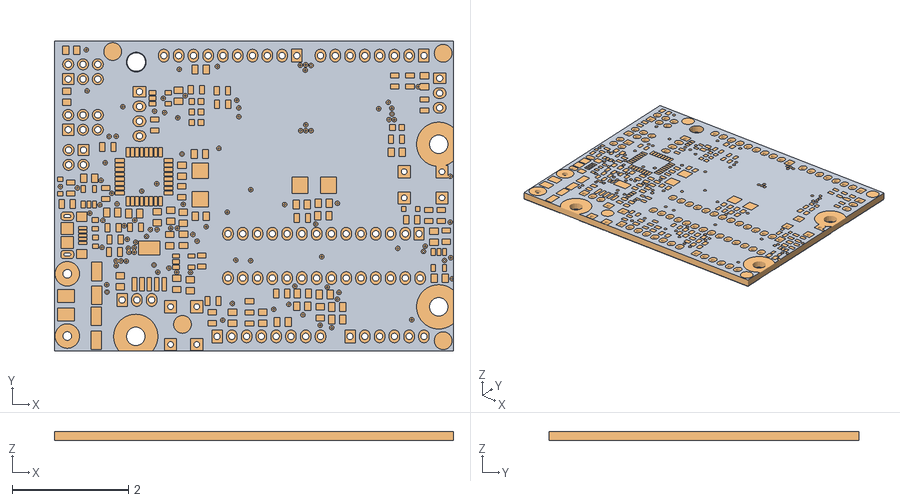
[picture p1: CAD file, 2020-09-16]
Design Files/28_Pin Project V1.1/28Pins_Project_1.1_PCB.obj
6.86 x 5.33 x 0.178
Solder_Top
Core
Solder_Bottom

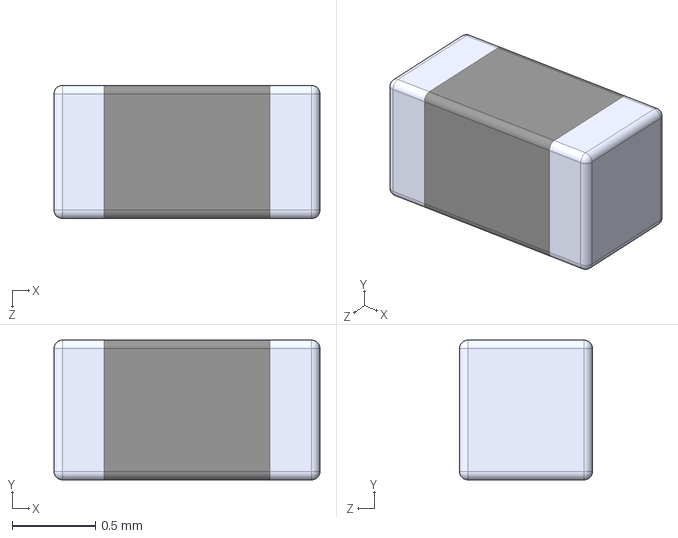
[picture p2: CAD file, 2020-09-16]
3D Component Models/R0603.step
1.60 x 0.84 x 0.8 mm

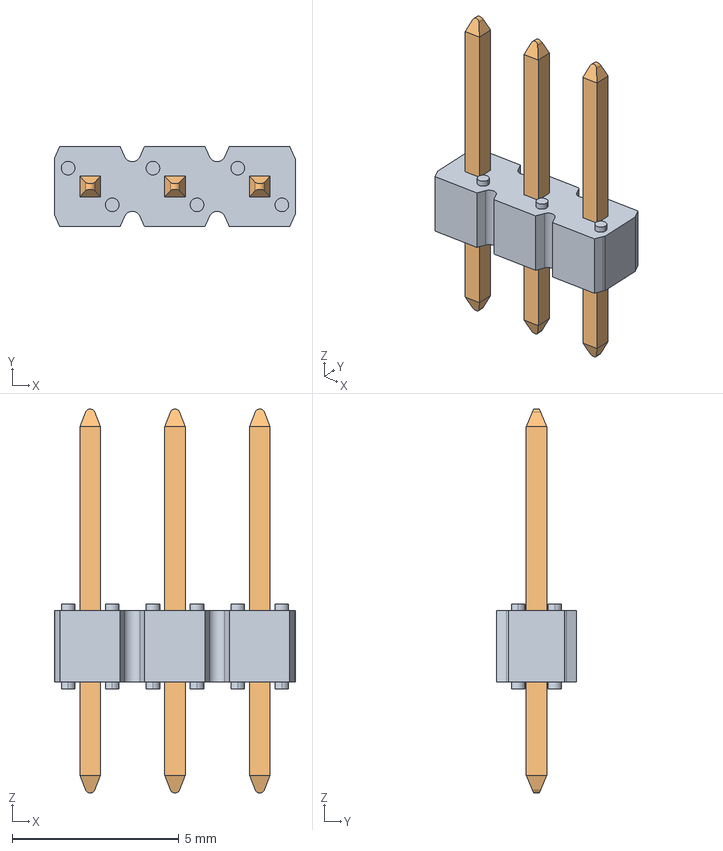
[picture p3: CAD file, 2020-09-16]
3D Component Models/HDR_1x3_White.stp
7.22 x 2.41 x 11.5 mm
77310_Y16 x 3

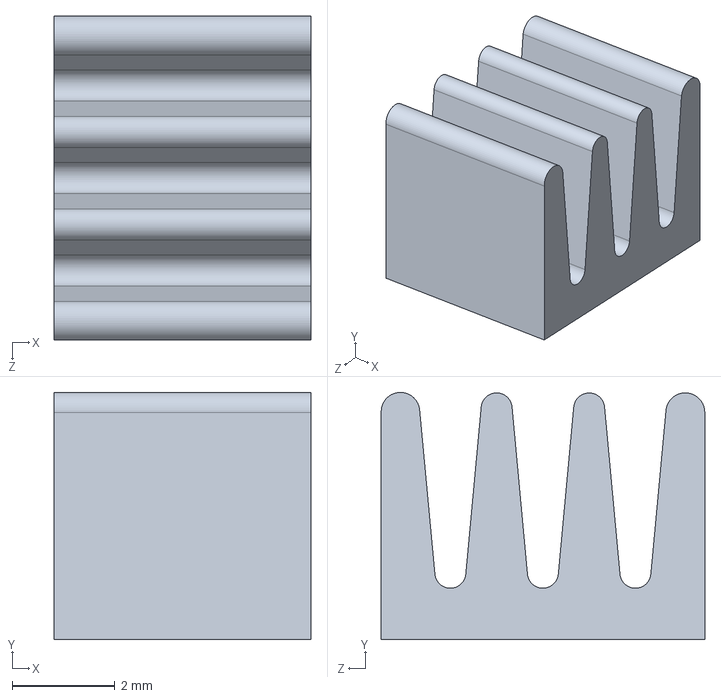
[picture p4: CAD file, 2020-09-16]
3D Component Models/User Library-Heatsink 6_3x5 mm.step
5.00 x 4.81 x 6.30 mm

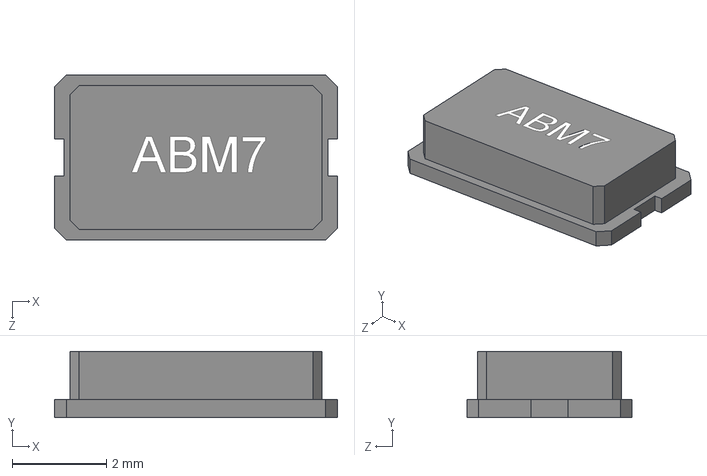
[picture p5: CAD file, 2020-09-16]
3D Component Models/ABM7_Crystal.STEP
5.99 x 1.40 x 3.51 mm

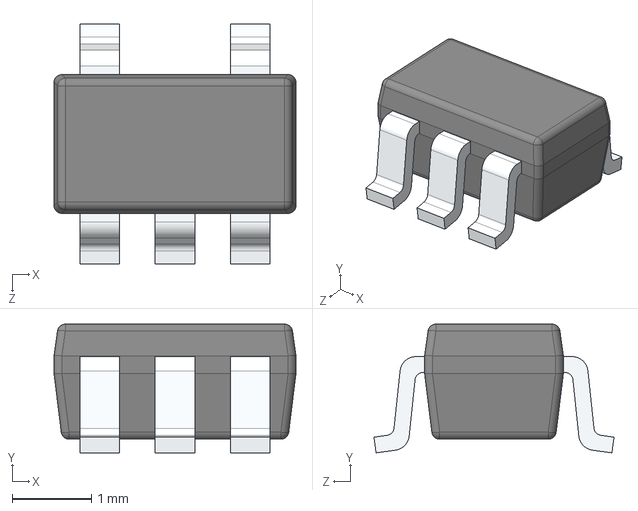
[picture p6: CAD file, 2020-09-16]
3D Component Models/DBV.step
3.05 x 1.62 x 3.03 mm

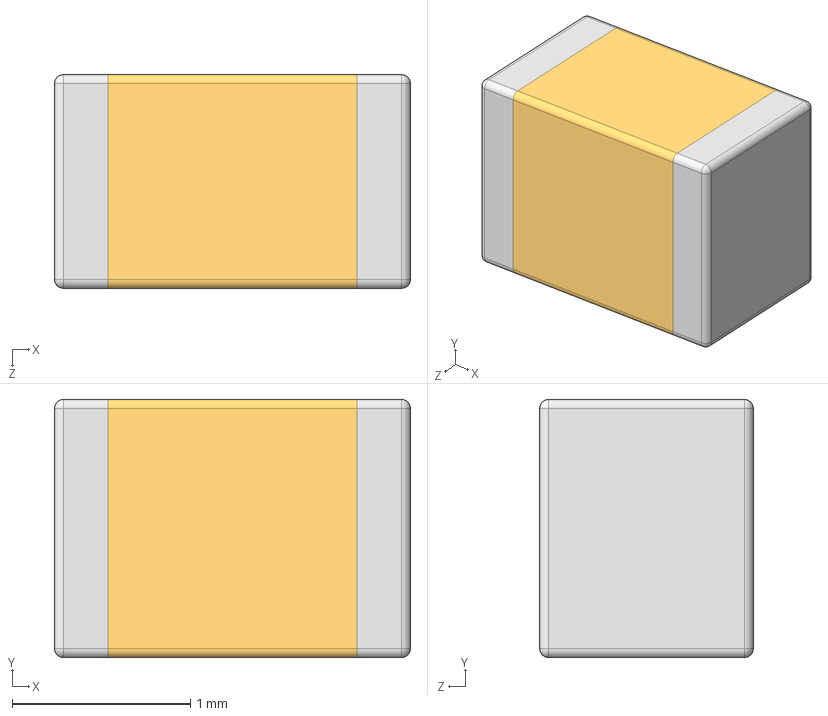
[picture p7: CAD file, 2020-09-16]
3D Component Models/CAPC2012X145N EIA 0805.step
2.00 x 1.45 x 1.20 mm

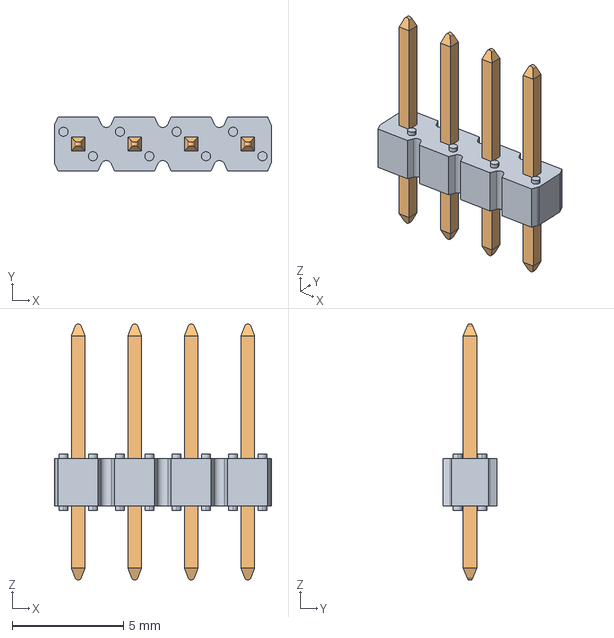
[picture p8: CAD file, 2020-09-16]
3D Component Models/HDR_1x4_White.stp
9.76 x 2.41 x 11.5 mm

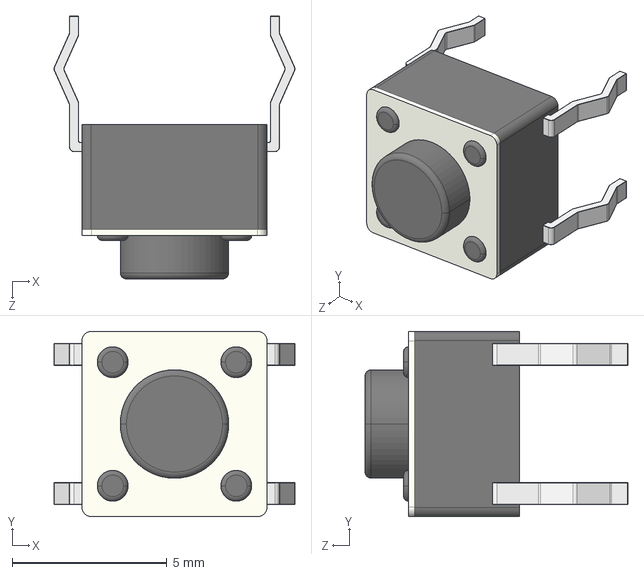
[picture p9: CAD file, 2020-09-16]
3D Component Models/FSM4JLH(1825910-5).step
7.80 x 5.99 x 8.51 mm

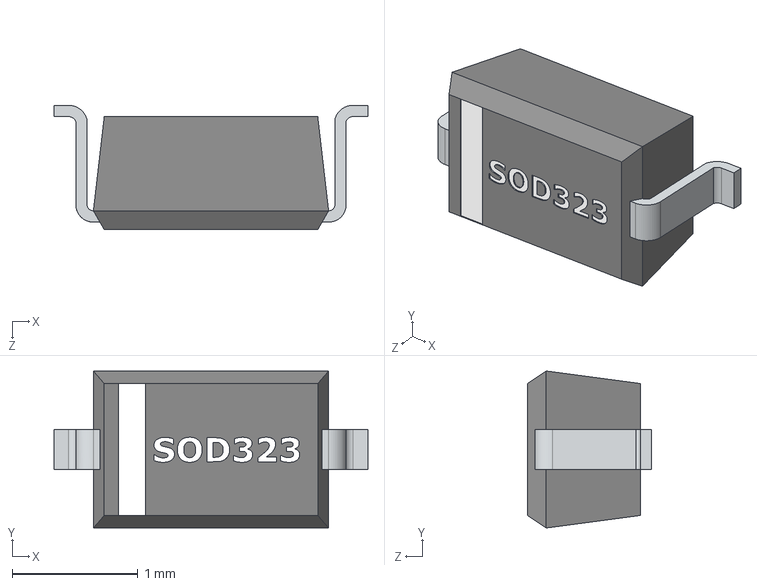
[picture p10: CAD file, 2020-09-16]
3D Component Models/User Library-SOD323.step
2.50 x 1.25 x 0.99 mm

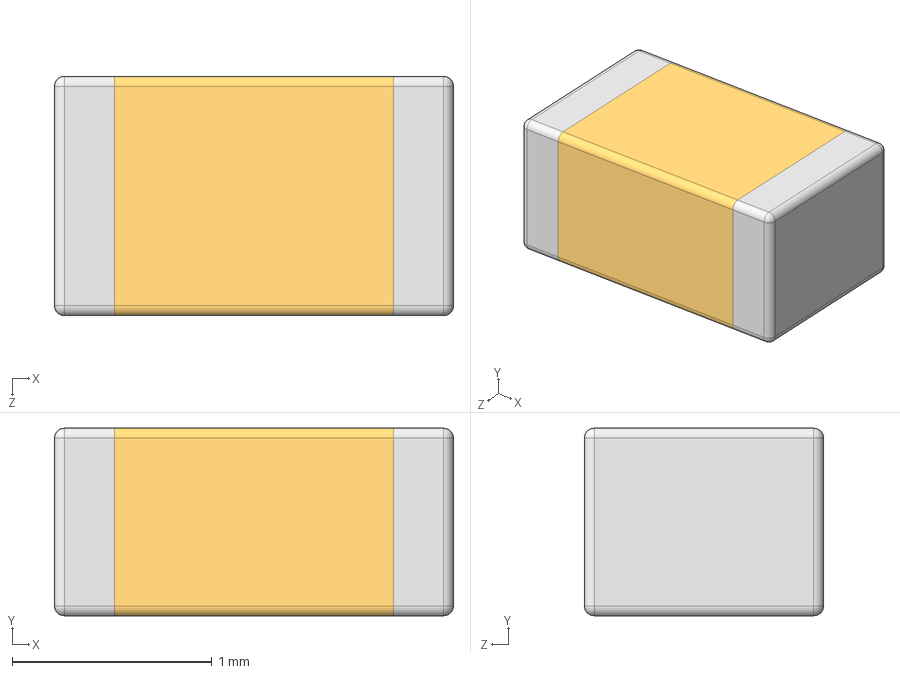
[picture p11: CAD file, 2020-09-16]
3D Component Models/CAPC2012X94N EIA 0805.step
2.00 x 0.94 x 1.20 mm

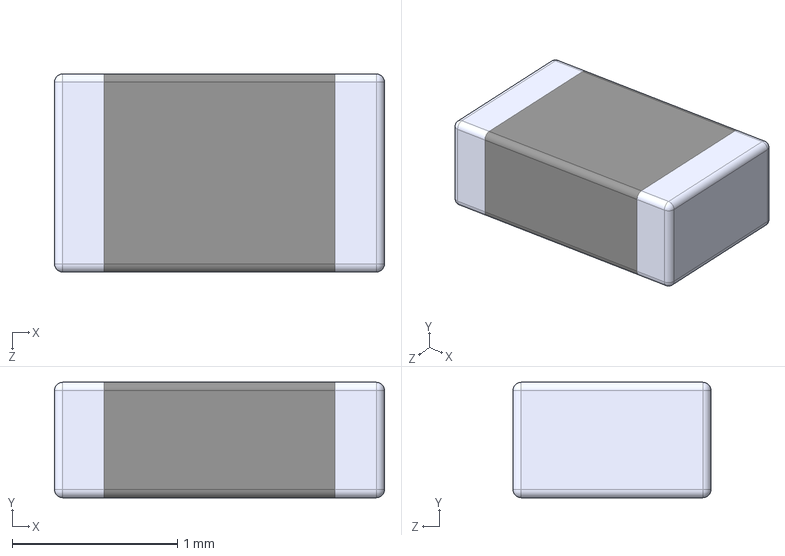
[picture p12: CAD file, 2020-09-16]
3D Component Models/User Library-Chip Resistor2.step
2.00 x 0.7 x 1.20 mm

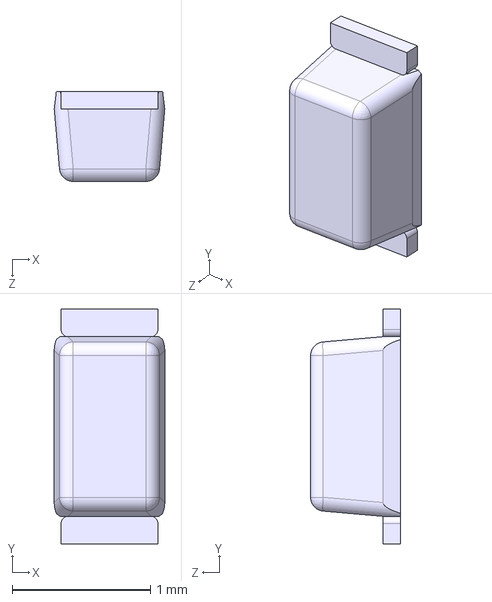
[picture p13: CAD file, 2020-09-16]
3D Component Models/User Library-LED SMD 0603 super red.step
0.8 x 1.70 x 0.65 mm

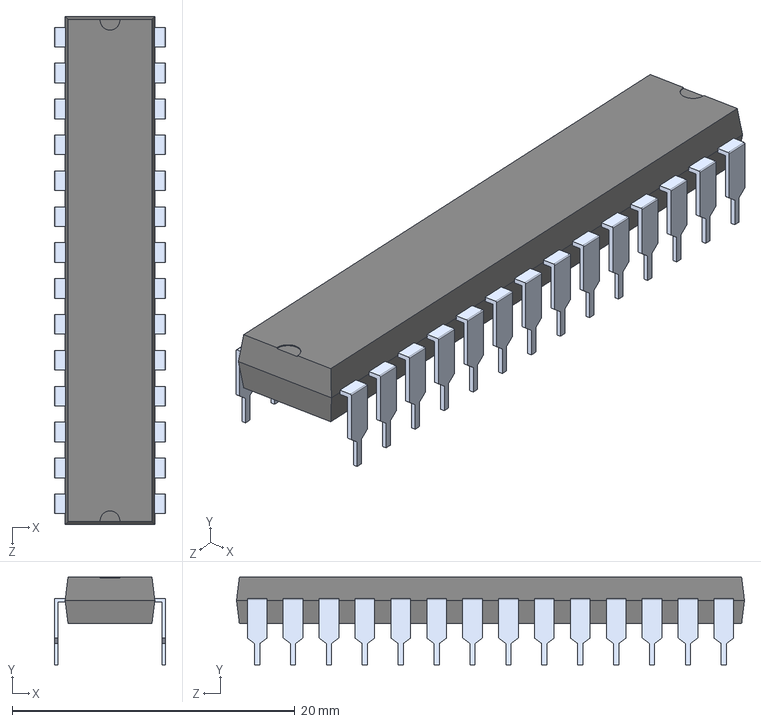
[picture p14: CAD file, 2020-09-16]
3D Component Models/3D_Model_ATMEGA328P-PU.step
7.87 x 6.22 x 35.9 mm

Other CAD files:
3D Component Models/3D_Model_ATMEGA16U2-AU.step
3D Component Models/dil_socket.stp
3D Component Models/capacitor size C.step
3D Component Models/m20-7820842_asm.stp
3D Component Models/961204-6404-XX-header2x2.stp
3D Component Models/961206-6404-XX-header3x2.stp
3D Component Models/M20-7820646.stp
3D Component Models/TPS73701DCQ.step
3D Component Models/m20-7821046_asm.stp

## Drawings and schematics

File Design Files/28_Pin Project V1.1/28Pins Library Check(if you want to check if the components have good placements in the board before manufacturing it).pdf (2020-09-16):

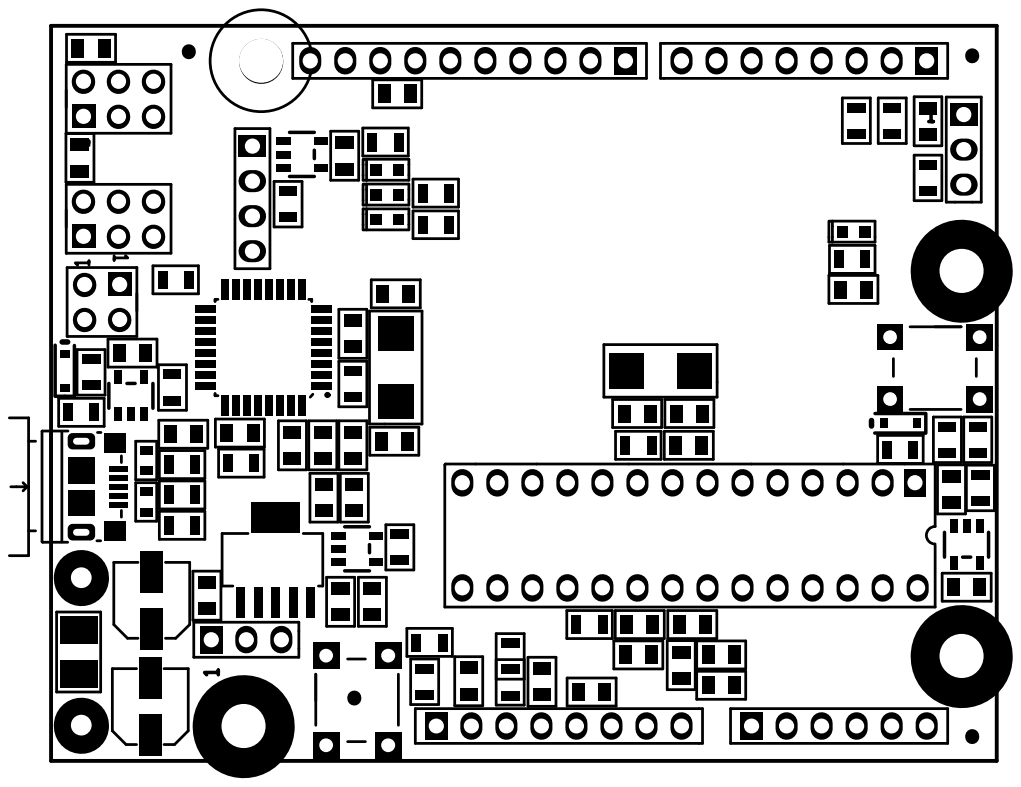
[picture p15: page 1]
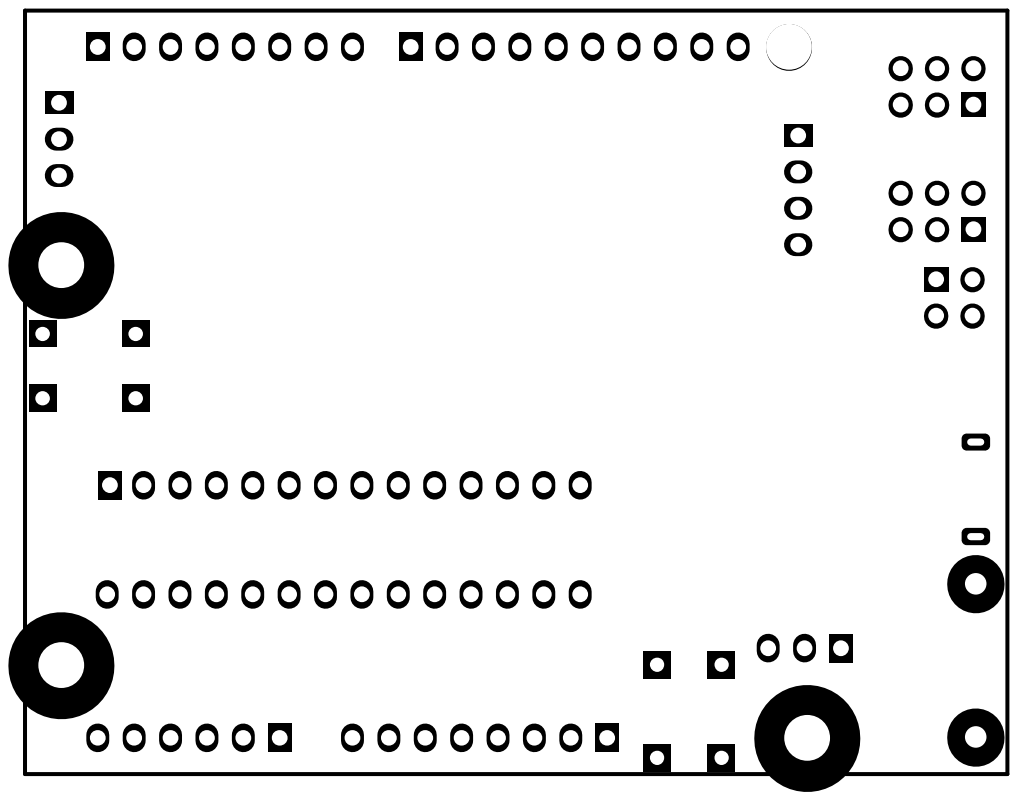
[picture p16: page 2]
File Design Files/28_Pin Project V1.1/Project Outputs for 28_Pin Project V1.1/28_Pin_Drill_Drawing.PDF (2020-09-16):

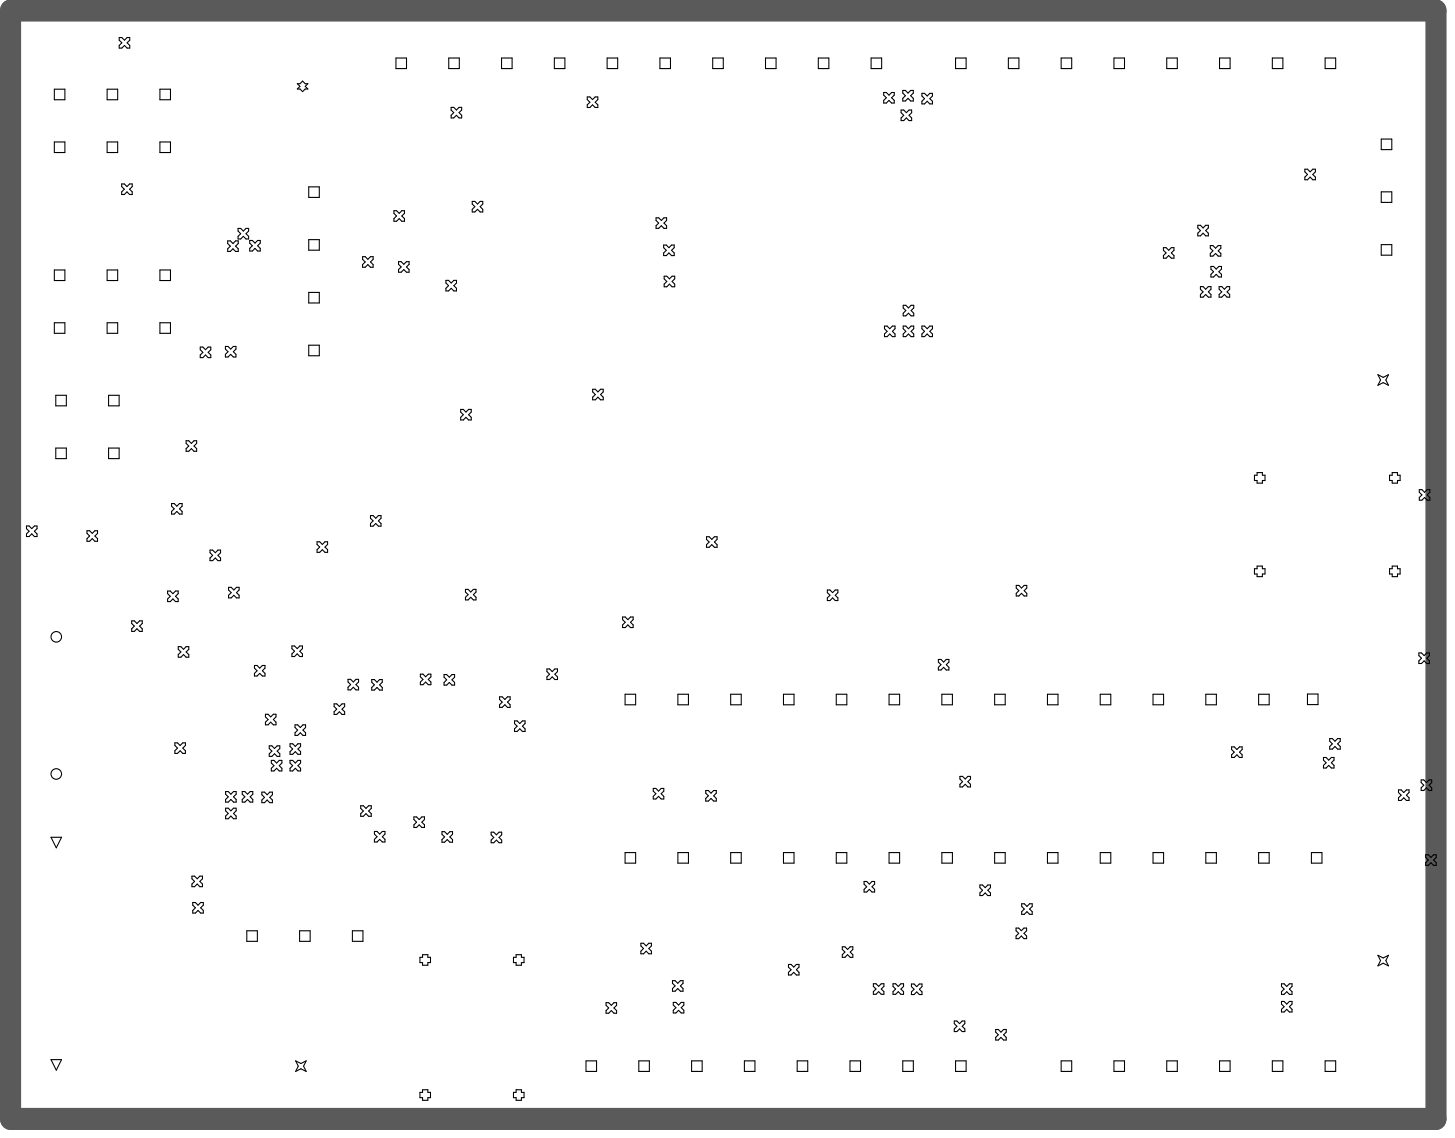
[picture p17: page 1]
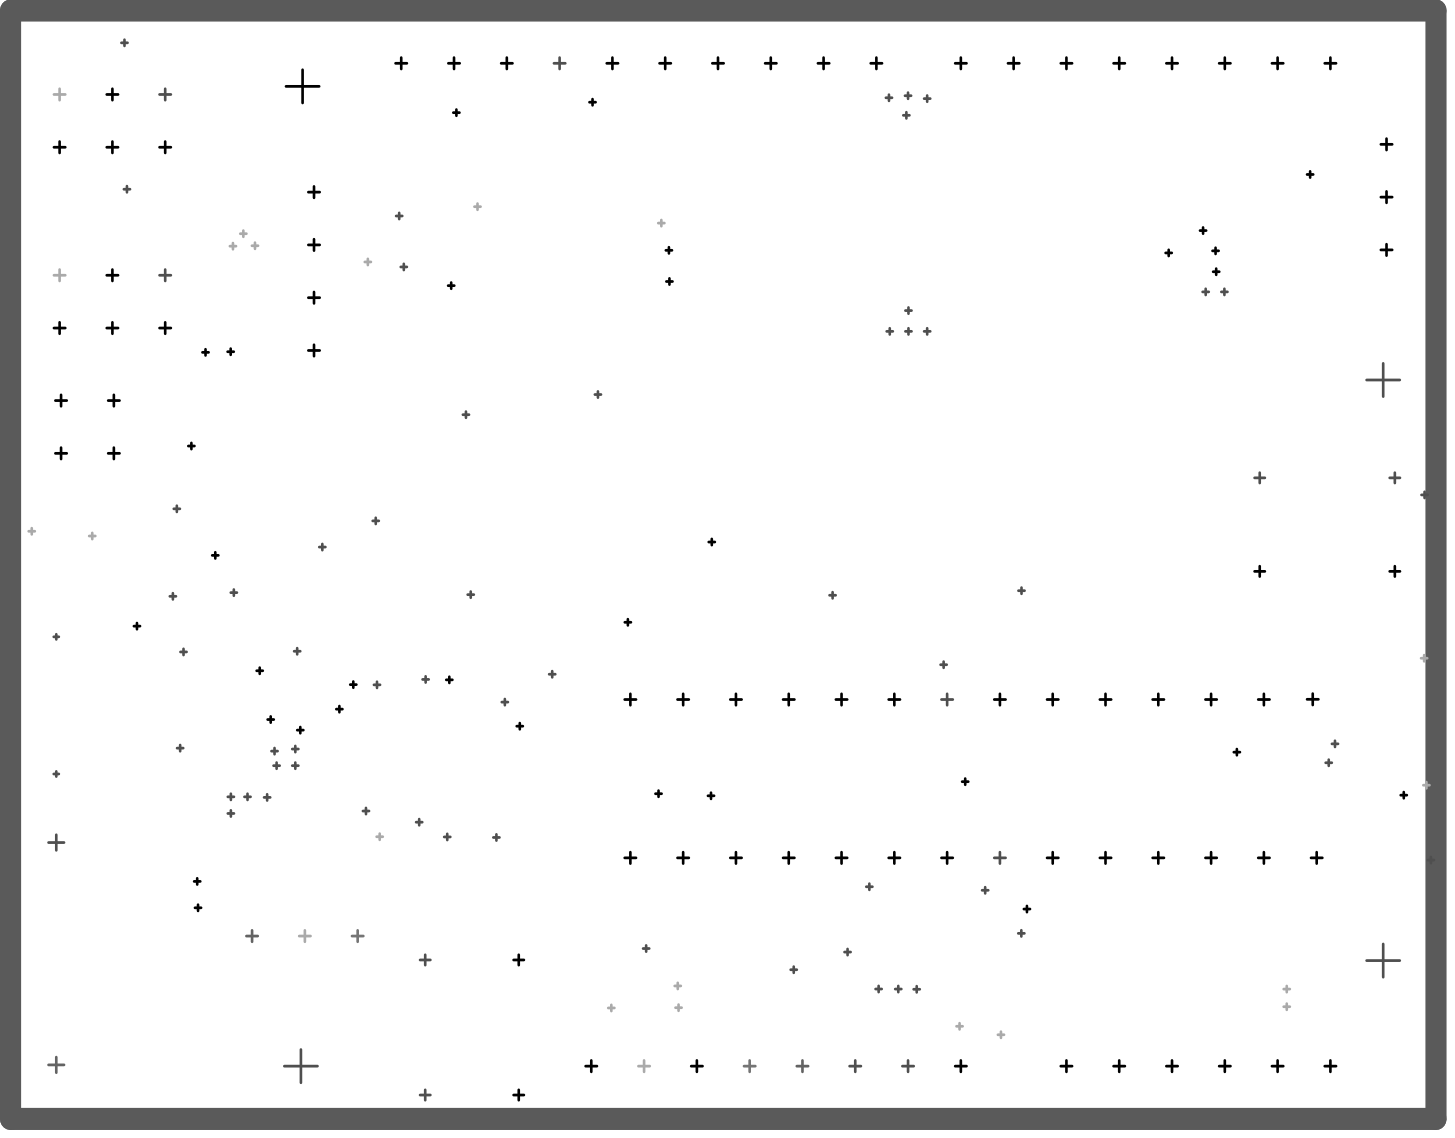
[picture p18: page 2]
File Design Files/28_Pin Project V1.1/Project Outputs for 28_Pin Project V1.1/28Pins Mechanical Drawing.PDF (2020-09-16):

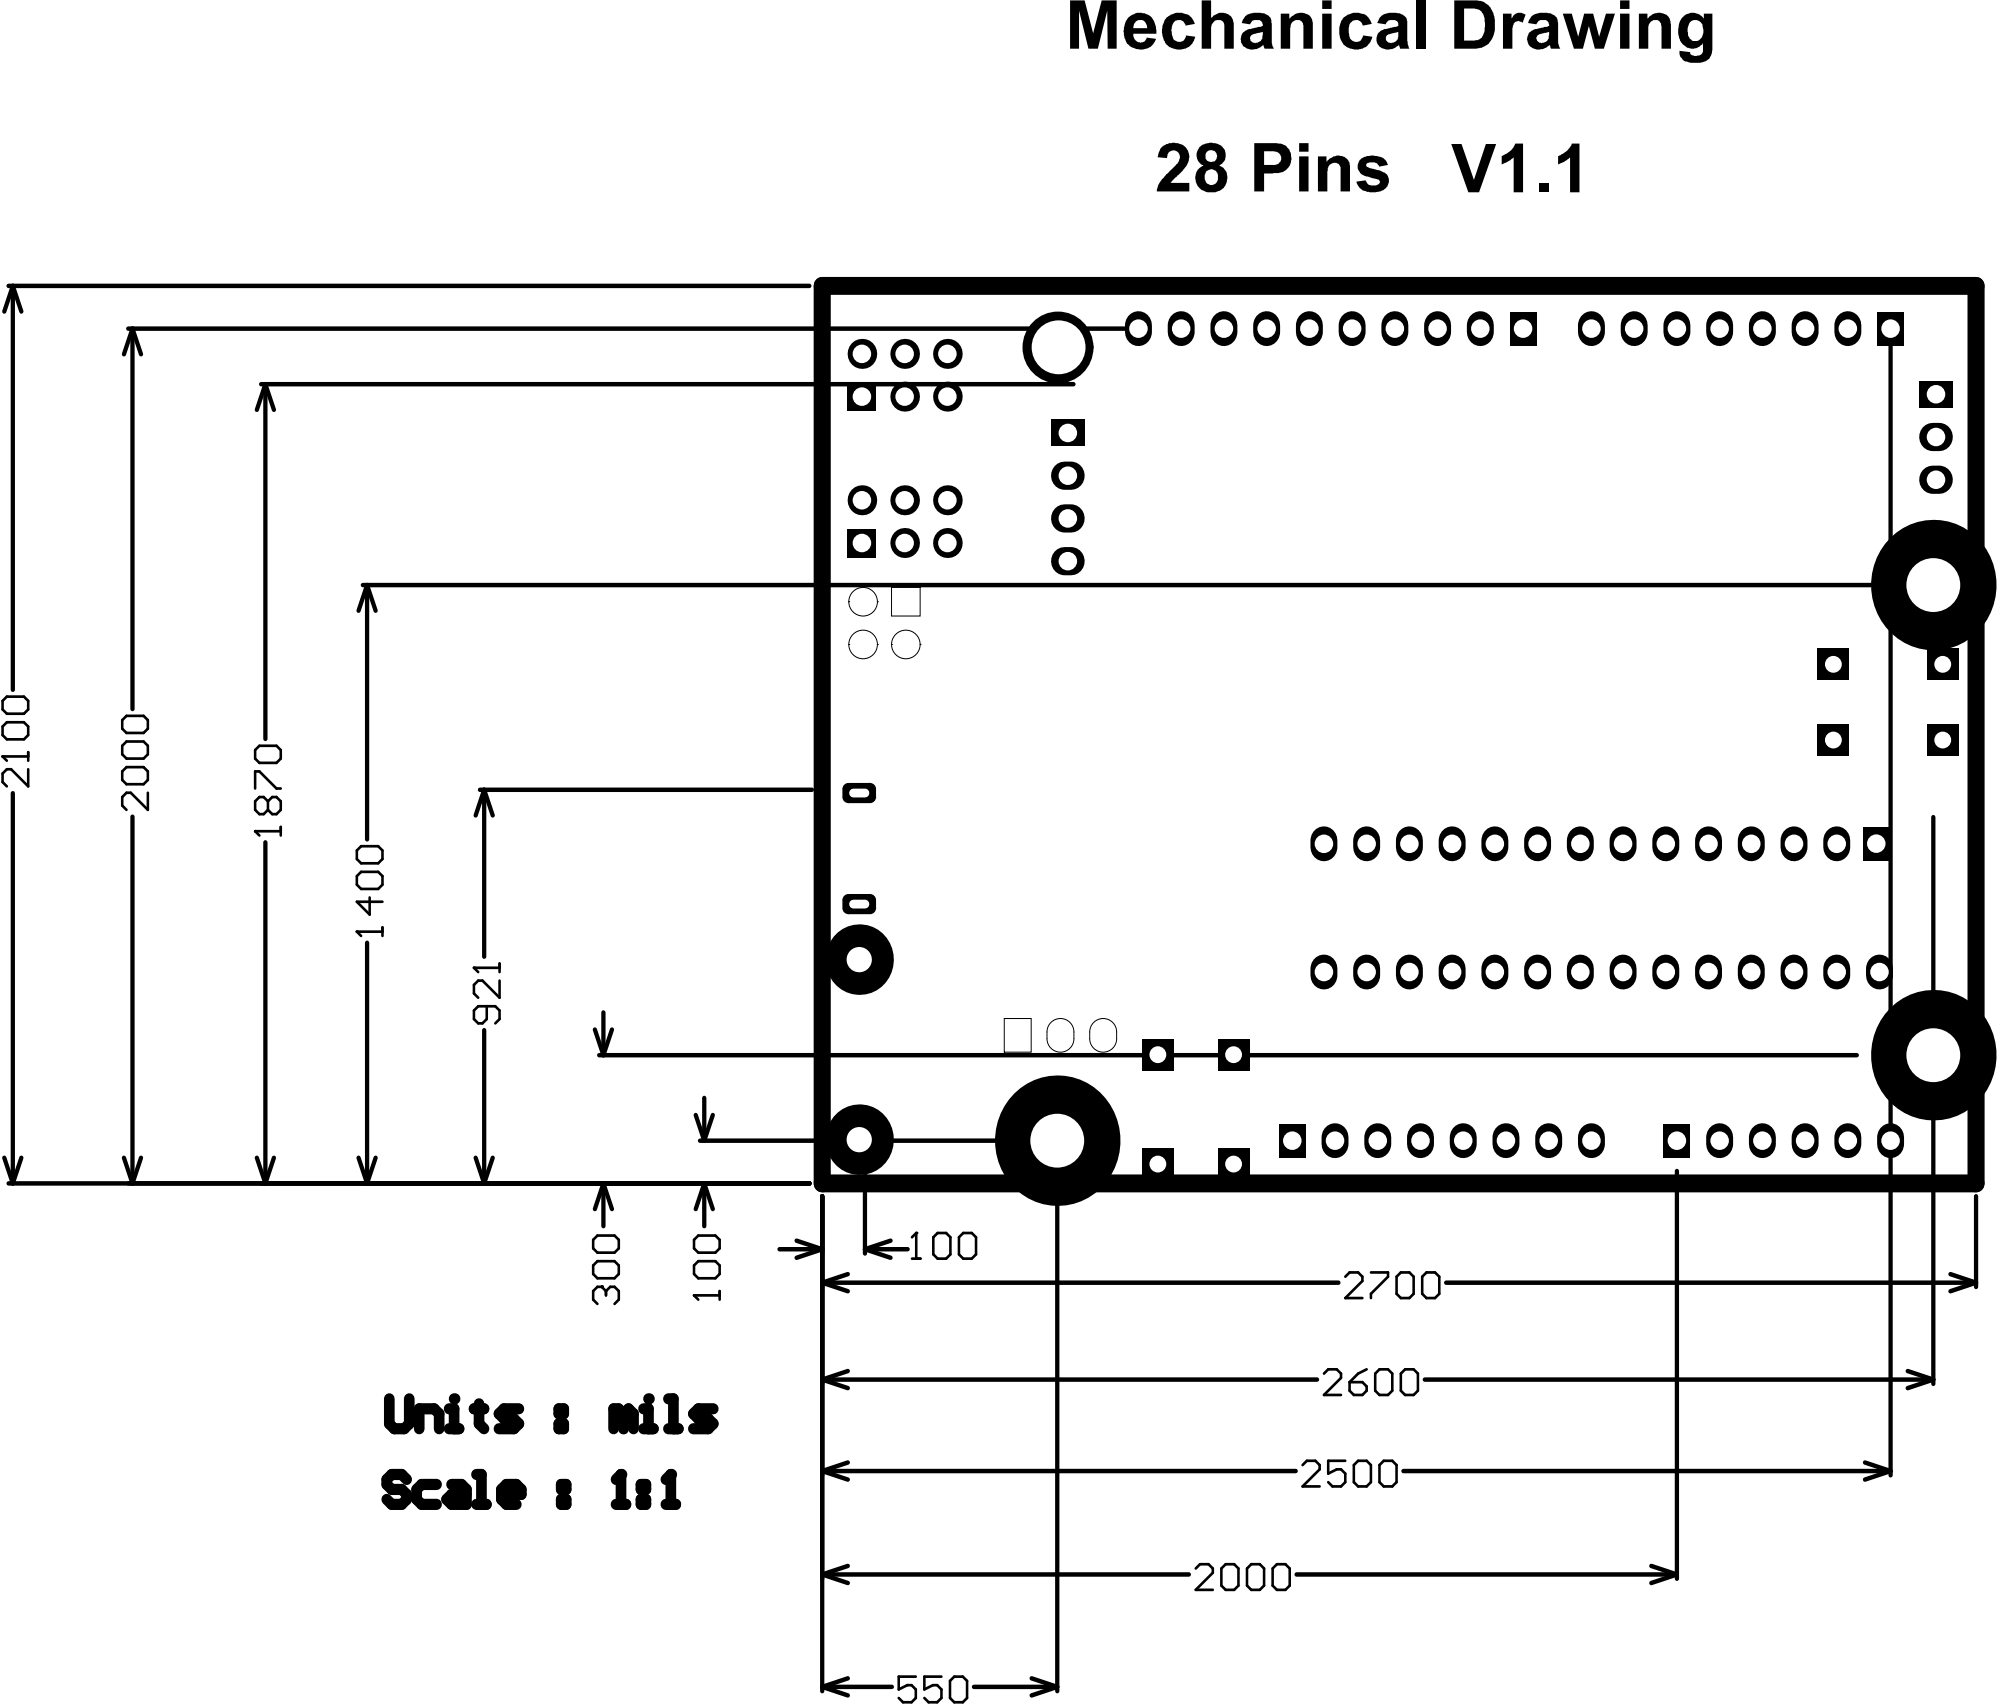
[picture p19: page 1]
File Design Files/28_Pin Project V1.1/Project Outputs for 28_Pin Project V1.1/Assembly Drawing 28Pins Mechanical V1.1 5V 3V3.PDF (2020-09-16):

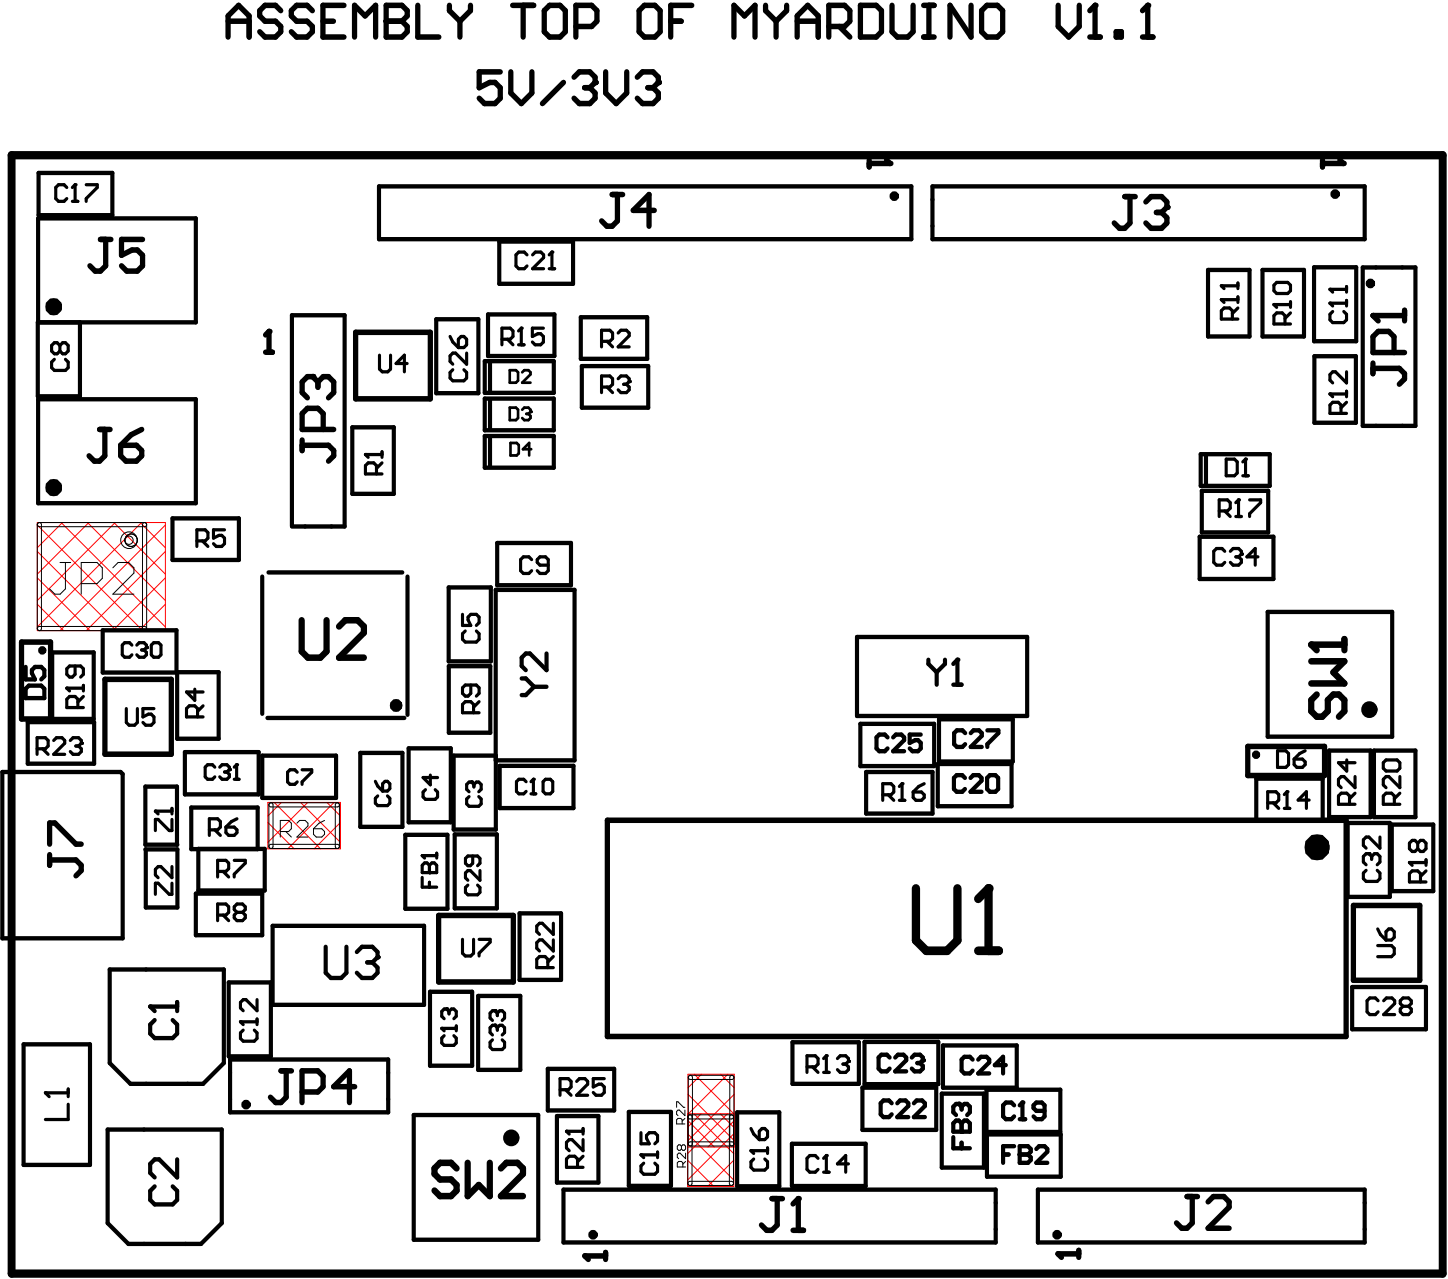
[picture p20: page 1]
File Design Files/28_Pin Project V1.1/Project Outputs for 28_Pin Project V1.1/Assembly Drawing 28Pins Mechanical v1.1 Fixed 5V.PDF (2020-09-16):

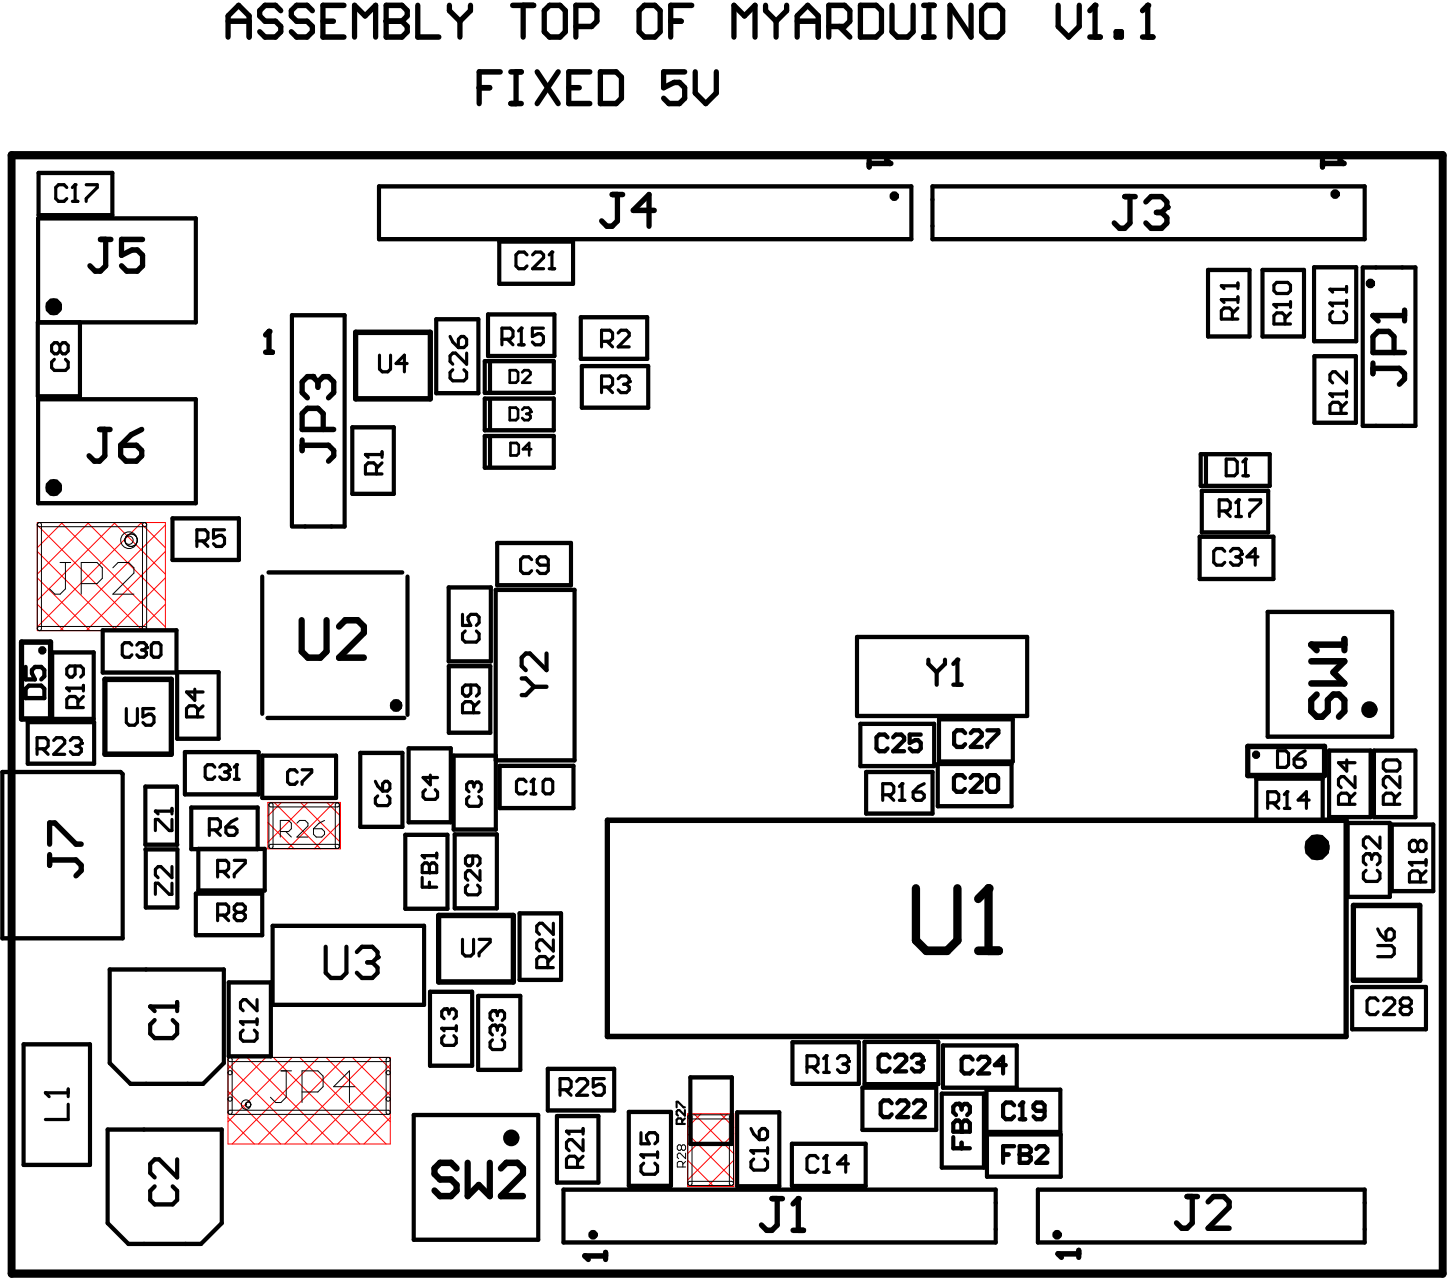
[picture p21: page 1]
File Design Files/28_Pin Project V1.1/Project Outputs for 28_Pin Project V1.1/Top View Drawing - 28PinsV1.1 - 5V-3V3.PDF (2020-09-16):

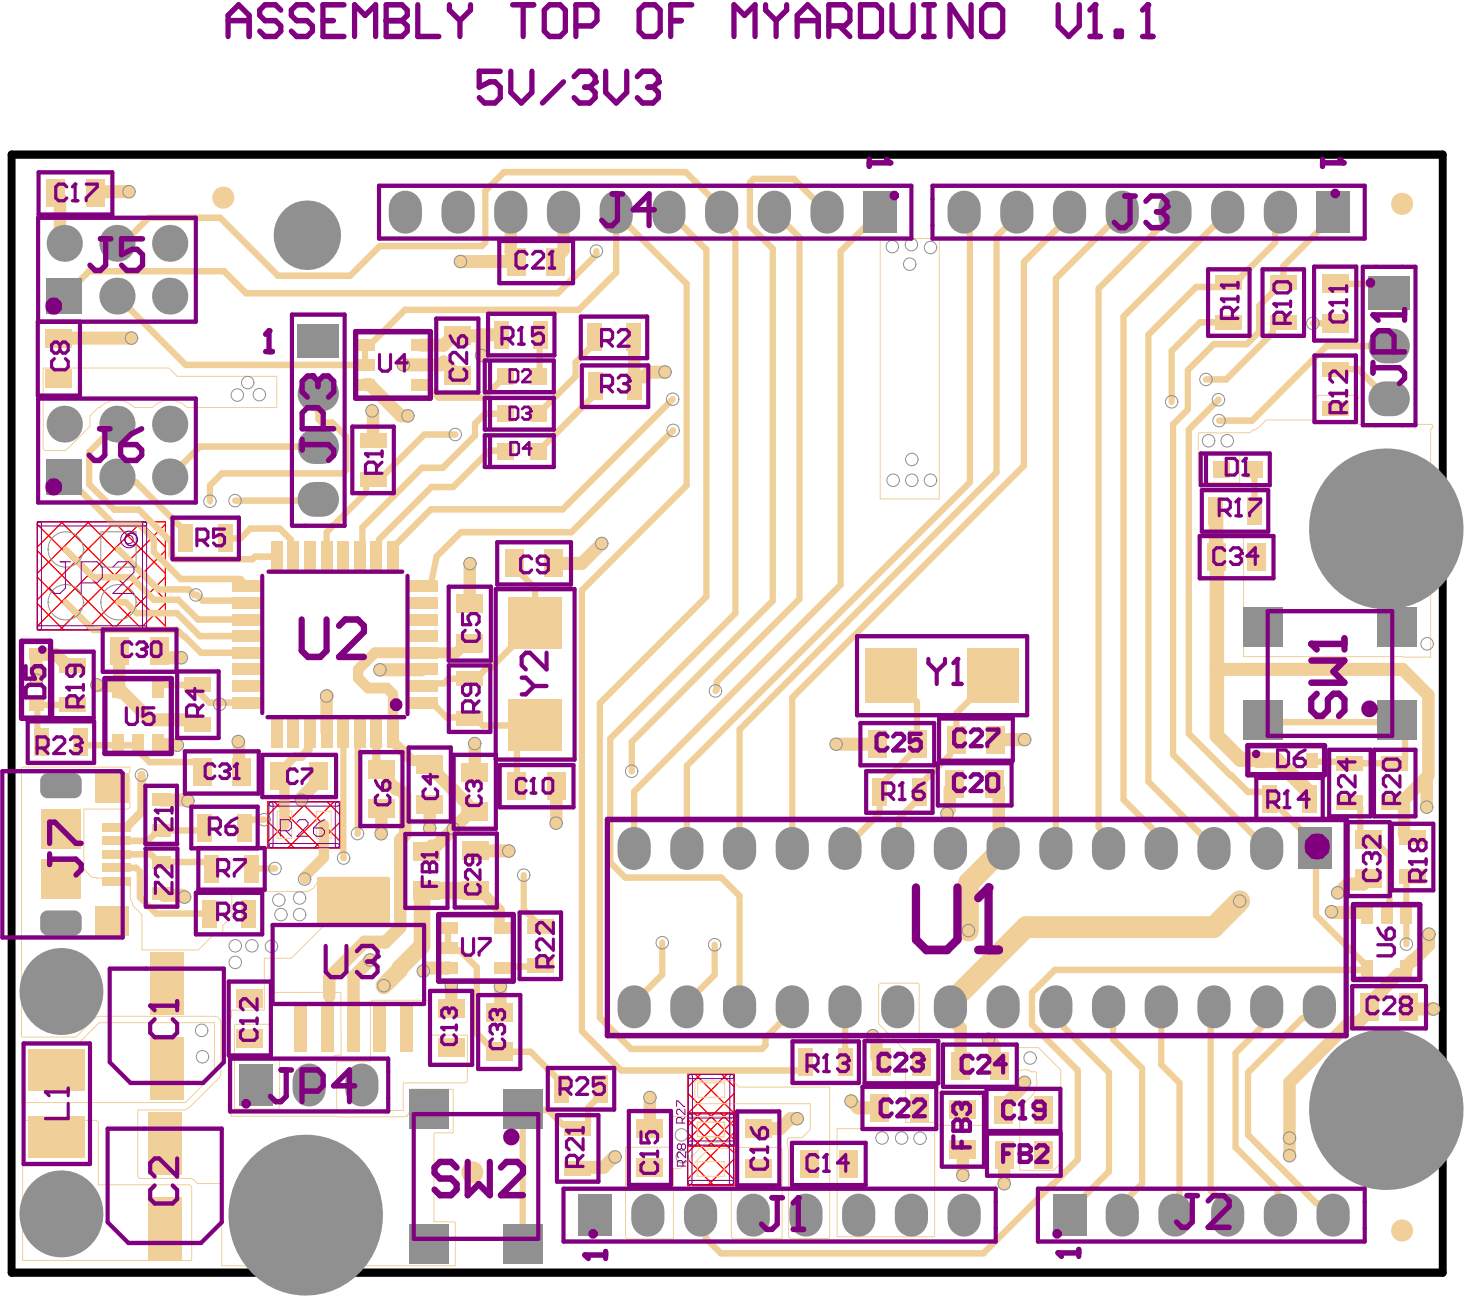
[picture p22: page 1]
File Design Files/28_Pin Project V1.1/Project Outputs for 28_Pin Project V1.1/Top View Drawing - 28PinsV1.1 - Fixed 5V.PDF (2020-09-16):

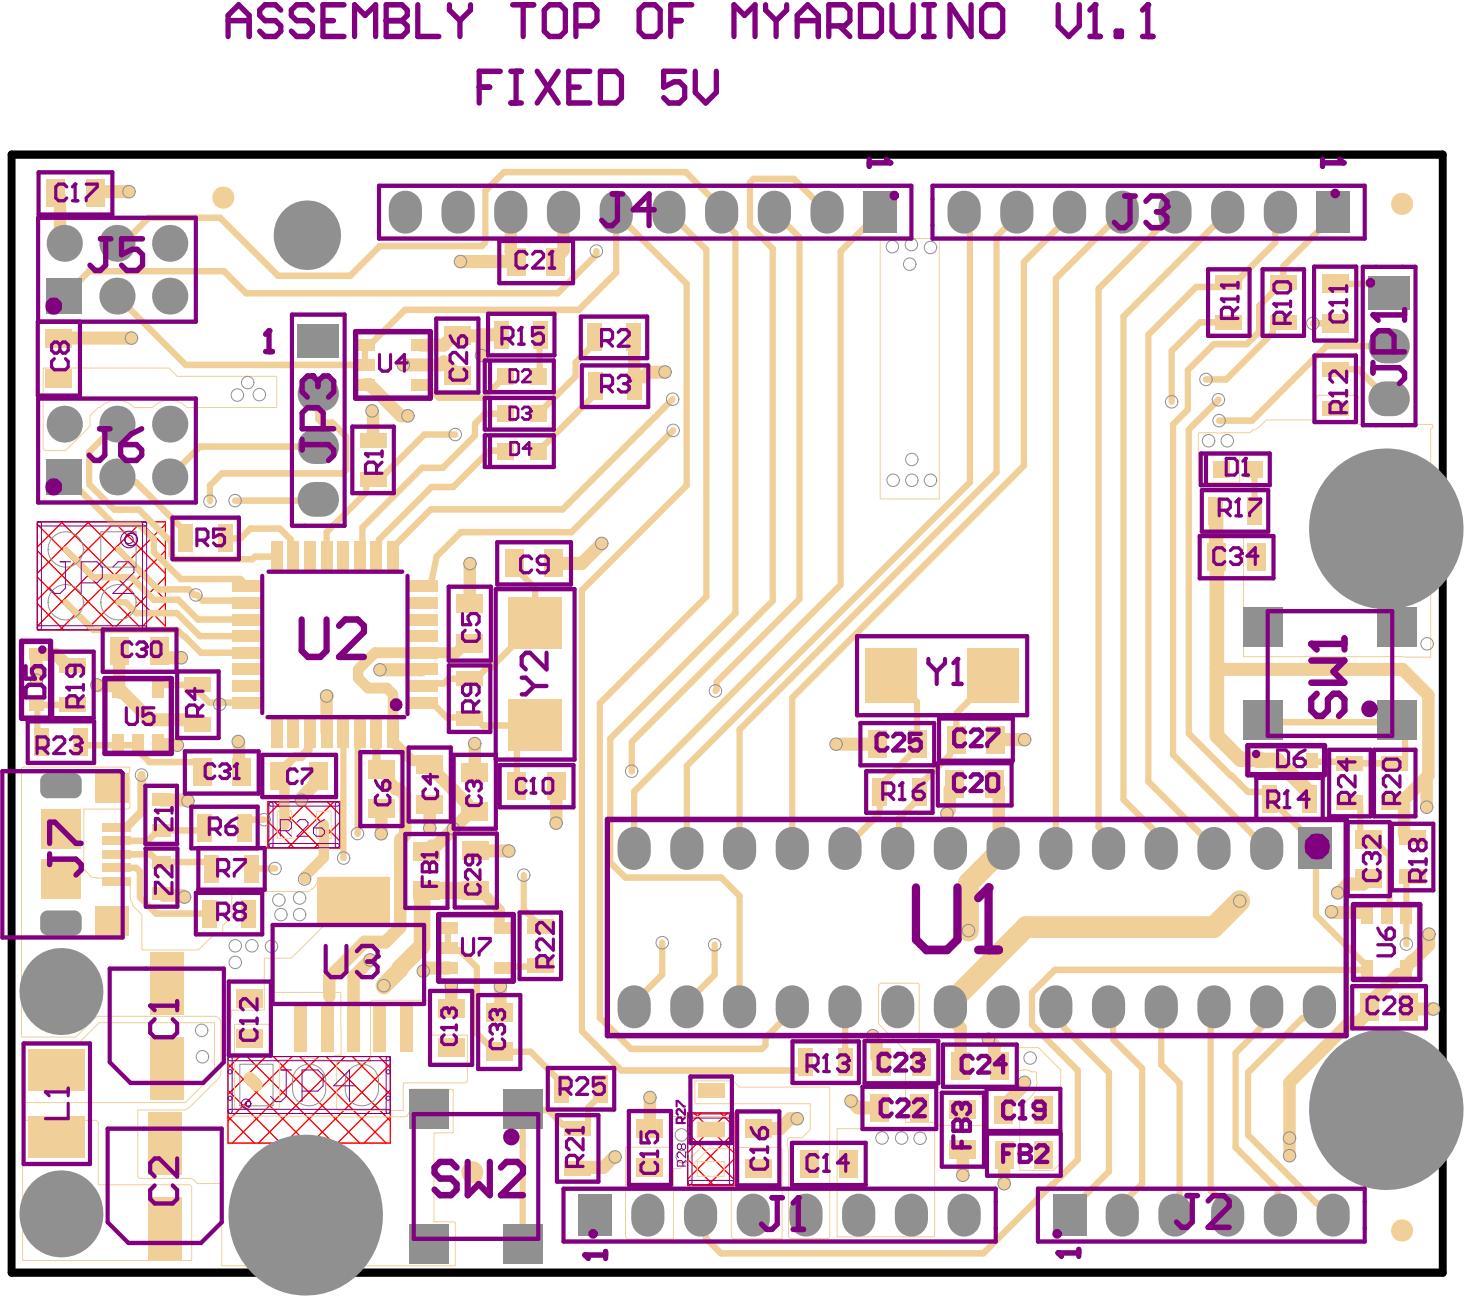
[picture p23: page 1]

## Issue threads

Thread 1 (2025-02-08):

Creating the Schematic

JakobMurray05, 2025-02-08:
I was curious how you created the schematic. Did you follow a specific design? I noticed some of the wiring looks different (more resistors here and there and different value components) vs the schematics for the Uno I find online. Thanks.
